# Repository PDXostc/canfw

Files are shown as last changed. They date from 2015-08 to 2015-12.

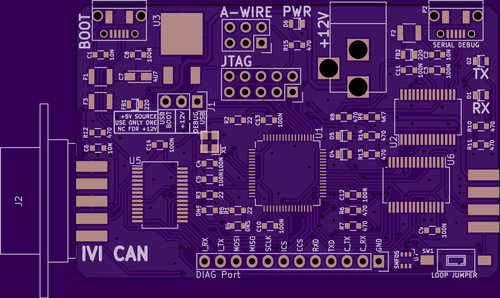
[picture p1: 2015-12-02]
hardware/Project Shares/V1.1 front.png

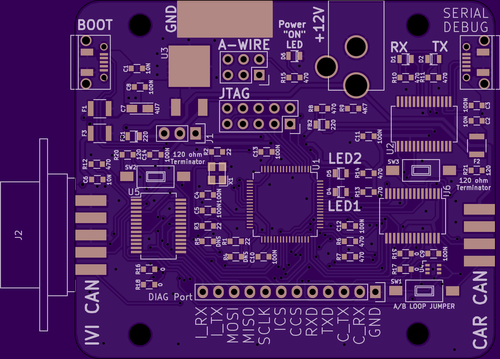
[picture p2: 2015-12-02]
hardware/Project Shares/V1.11 front.png

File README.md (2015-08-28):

# CAN FIREWALL

There are two tables, IVI2VEH and VEH2IVI, specifiying rules for
traffic going from the IVI to the vehicle and from vehicle to IVI.

Each one of the two tables has a number of rules.

Each rule has a numberic ID. Rules are executed in order of ascending IDs.

Each rule has an Frame ID mask and a Frame ID filter, applied
according to the standard CAN bus filter principle, as described 
[here](http://www.cse.dmu.ac.uk/~eg/tele/CanbusIDandMask.html).

Below is pseudo code for frame processing.

    process_frame(frame_id, payload) {

      // Traverse all rules
      for (i in rules) {
	    masked_id = (frame_id & rules[i].id_mask);

	    // If the masked out ID is 0, we have a hit. Process
        if (!masked_id) {
	      process(frame_id, input, rules[i].action,
		          rules[i].id_operand, rules[i].data_operand);
	      return;
	    }

        // Check if we have a hit on the masked ID and the
		// ID filter.
	    // If so, we have a hit and will process
	    if (masked_id & rules[i].id_filter) {
	      process(frame_id, input, rules[i].action,
		          rules[i].id_operand, rules[i].data_operand);
	      return;
	    }

        // No hit. Try next rule
	  }

	  // No rule matched. Forward unmodified frame
      process(frame_id, input, ID_AND_DATA_AND,
	          0xFFFFFFFF, 0xFFFFFFFFFFFFFFFF);

	  return ok;
    }

Below is an example of a rule table.

ID | IdMask     |   IdFilter | Action          | IdOperand  | DataOperand        |
---|------------|------------|-----------------|------------|--------------------|
1  | 0xFFFFFFFF | 0x00000012 | ID_AND_DATA_OR  | 0x00FFFFFF | 0x000000FFFFFFFFFF |
2  | 0xFFFFFFF0 | 0x00000120 | ID_SET_DATA_SET | 0x01234567 | 0x0123456780ABCDEF |
99 | 0x00000000 | 0x00000000 | BLOCK           | 0x00000000 | 0x0000000000000000 |

* **RULE 1**<br>
  Rule ID 1 specifies will filter out the lower all bits of the CAN
  frame ID and match those against the specific ID 0x12, thus intercepting
  all CAN frames with the exact ID of 0x00000012.<br>
  An intercepted frame will be forwarded to the other side after ANDing
  the incoming Frame ID with ```0x00FFFFFF```, and then ORing the
  data payload with ```0x000000FFFFFFFFFF```.<br>
  Once the intercepted frame has been forwarded, the next frame is processed.

* **RULE 2**<br>

  Rule ID 2 is evaluated for all frames not intercepted by Rule 1 above.
  The rule will mask the incoming CAN frame ID against ```0xFFFFFFF0```
  and filter the result against ```0x00000120```, intercepting all
  CAN frames between ```0x00000120``` and ```0x0000012F```.<br>
  For each frame intercetpted by rule 2, a fixed frame will be sent to the other side
  with the frame ID ```0x01234567``` and payload ```0x0123456780ABCDEF```.

* **RULE 99**<br>
  Rule 99, a catch all, has a mask that intercepts all frames not intercepted
  by rule 1 or 2. Since the mask is ```0x00000000```, the filter will not be
  used since there no bits will pass the mask to be applied to the filter.<br>
  Rule 99 will block the frame and not send anything to the other side.<br>
  The modification bitmasks for the frame ID and data payload are unused 
  for blocking rules.

Please see presentation under doc for further details.

Hardware Details and Data sheets:
AT32UC3C2512C Datasheet http://www.mouser.com/ds/2/36/doc32117-74889.pdf

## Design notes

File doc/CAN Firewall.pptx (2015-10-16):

## CAN Bus Firewall

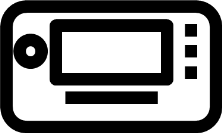
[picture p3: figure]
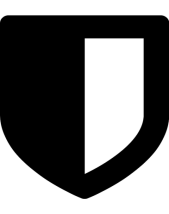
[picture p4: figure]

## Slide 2

Purpose

Ensure compromised IVIs
cannot disrupt
safety critical systems

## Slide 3

Overview

IVI

CAN
Firewall

ECU 1

ECU 2

IVI
Runs a wide variety of software that may be compromised through telematics link
CAN Firewall
Hardware microcontroller on CAN bus filtering CAN traffic based on configurable rules
ECUs
Safety-critical vehicle controllers managing breaks, throttle, steering, etc.

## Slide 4

Northbound vs. Southbound Traffic

Northbound traffic

Forward CAN frame to IVI

Validate CAN frame against rule table

Receive CAN Frame from Vehicle

Southbound traffic

Receive CAN frame from IVI

Validate CAN frame against rule table

Forward CAN Frame to Vehicle

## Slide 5

Use Case: Update rules

A new firewall rule is created and is signed using device-specific key
Rule is pushed over the air to the IVI
IVI Firewall Manager forwards the signed rule to the firewall as a specific CAN frame
Firewall validates signature of received frame and stores new rule.

Backend Server

Rule Admin

Firewall Manager

IVI

Firewall

Rule Manager

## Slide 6

Rule Structure [1/2]

Mask | Filter | ID XForm | Data XForm | ID Operand | Data Operand
0xFFFFFFFF | 0x00000012 | AND | OR | 0x00FFFFFF | 0x000000FFFFFFFFFF

Only bits set in the mask will be matched against the filter
Filter
ANDed against the masked Frame ID of incoming frame
Frame IDs passing filter are intercepted
Frame ID of an incoming frame is masked against rule mask
Mask

See http://www.cse.dmu.ac.uk/~eg/tele/CanbusIDandMask.html for details

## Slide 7

Rule Structure [2/2]

Mask | Filter | ID XForm | Data XForm | ID Operand | Data Operand
0xFFFFFFFF | 0x00000012 | AND | OR | 0x00FFFFFF | 0x000000FFFFFFFFFF

ID XForm
Determines transformation applied to outbound Frame ID (SET, AND, OR, XOR, INV)
ID Operand
Transformation operand applied to outbound Frame ID
Data Operand
Transformation operand applied to outbound Data
Data XForm
Determines transformation applied to outbound Data (SET, AND, OR, XOR, INV)

A Rule can also specify that the frame is to be silently dropped or passed as is.

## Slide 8

CAN Rule Table

Prio | Mask | Filter | ID XForm | Data XForm | ID Operand | Data Operand
0x01 | 0xFFFFFFFF | 0x00000012 | AND | OR | 0x00FFFFFF | 0x000000FFFFFFFFFF
0x02 | 0xFFFFFFF0 | 0x00000120 | SET | SET | 0x01234567 | 0x0123456780ABCDEF
0x7E | 0x00000000 | 0x00000000 | DROP | DROP | 0x00000000 | 0x0000000000000000

Prioritize
Rules are applied to incoming frames in order of ascending priority
Match and process
A rule-matching frame is processed by that rule and is then forwarded to its destination
Forward to next rule
A non-matching frame passed on to the rule with the next ascending ID

If no rule matches, the frame is forwarded unmodified to its destination

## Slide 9

CAN Rule Configuration – Common Header

Frame ID | Data: Prio [1] | Data: Cmd [1] | … | …
0x00004711 | 0x04 | [RULE] | … | …

Frame ID [32 bits]
Factory-configured CAN Frame that is intercepted and interpreted by the CAN Firewall.
Prio [0x00-0x7F | 0x80-0xFF] [1 byte]
Specifies the priority of the rule that is being prepared and which .
0x00-0x7F applies to northbound traffic. 0x80-0xFF applies to southbound traffic.
All commands setting up and storing a single rule will use the same Prio.
Cmd [PREP_RULE1, PREP_RULE2, PREP_RULE3 , PREP_RULE4, PREP_RULE5,PREP_RULE6, STORE_RULE] [1 byte]
Sets up a single rule. PREP_RULE1 – PREP_RULE6 are transmitted with the same Prio. STORE_RULE is then transmitted with the given Prio to store the single rule specified by the previous PREP rule commands.

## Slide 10

CAN Rule Configuration – PREP_RULE1

Frame ID | Prio [1] | Cmd [1] | Mask [4] | XForm [1] | Rsvd [1]
0x00004711 | 0x04 | 0x01 | 0x0000FFFF | 0x01 | 0x00

Cmd [PREP_RULE1] [1 byte]
PREP_RULE1 specifies the rule priority and the mask to apply, and the transform operators for the rule.
XForm [SET_AND] [1 byte]
The transformation to apply to Frame ID and Data. Combination of SET, AND, OR, XOR, and NEG. Upper four bits defines Frame ID operator. Lower four bits defines Data operator.
Mask [32 bit value] [4 bytes]
Mask to apply to incoming Frame ID prior to filtering.
Reserved for future use. Set to 0

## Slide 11

CAN Rule Configuration – PREP_RULE2

Frame ID | Prio [1] | Cmd [1] | Filter [4] | DtOper1 [2]
0x00004711 | 0x04 | 0x02 | 0x0000AAC1 | 0x0001

Cmd [PREP_RULE2] [1 byte]
PREP_RULE2 specifies the filter to apply to incoming Frame IDs and the low 16 bits of the Data transformation operand
DtOper1 [16 bit value] [2 bytes]
Specifies the little endian bits 0-15 of the data operand to provide to the data transform operator (AND, OR, XOR, NEG).
Filter [4] [32 bit value] [4 bytes]
Filter to apply to incoming Frame ID that has been masked.

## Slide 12

CAN Rule Configuration – PREP_RULE3

Frame ID | Prio [1] | Cmd [1] | DtOper2 [6]
0x00004711 | 0x04 | 0x03 | 0x020304050607

Cmd [PREP_RULE3] [1 byte]
PREP_RULE2 specifies the high 48 bits of the operand to apply to the payload transform operator.
DtOper2 [48 bit value] [6 bytes]
Specifies little endian bits 16-63 of the data operand to provide to the data transform operator (AND, OR, XOR, NEG).
DtOper1 and DtOper2 in the example above are concatenated to: 0x0706050403020100

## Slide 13

CAN Rule Configuration – PREP_RULE4

Frame ID | Prio [1] | Cmd [1] | IDOper [4] | HMAC1 [2]
0x00004711 | 0x04 | 0x04 | 0xFFFF0000 | 0x0001

Cmd [PREP_RULE4] [1 byte]
Specifies the Frame ID operand and the lowest2 bytes of the HMAC-SHA256 signature
HMAC1 [16 bit value] [2 bytes]
Specifies little endian bits 0-15 bits of the HMAC-SHA256 signature, generated with the key flashed into the Firewall at the factory.
IDOper [32 bit value] [4 bytes]
Specifies the Frame ID operand to provide to the Frame ID transform operator

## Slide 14

CAN Rule Configuration – PREP_RULE5

Frame ID | Prio [1] | Cmd [1] | HMAC2 [6]
0x00004711 | 0x04 | 0x05 | 0x020304050607

Cmd [PREP_RULE5] [1 byte]
Specifies six bytes of the HMAC-SHA256 signature
HMAC2 [48 bit value] [6 bytes]
Specifies little endian bits 16-63 of the HMAC-SHA256 signature

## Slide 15

CAN Rule Configuration – PREP_RULE6

Frame ID | Prio [1] | Cmd [1] | HMAC3 [6]
0x00004711 | 0x04 | 0x06 | 0x08090A0B0C0D

Cmd [PREP_RULE6] [1 byte]
Specifies six bytes of the HMAC-SHA256 signature
HMAC3 [48 bit value] [6 bytes]
Specifies little endian bits 64-111 of the HMAC-SHA256 signature

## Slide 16

CAN Rule Configuration – PREP_RULE7

Frame ID | Prio [1] | Cmd [1] | HMAC4 [6]
0x00004711 | 0x04 | 0x07 | 0x0E0F10111213

Cmd [PREP_RULE7] [1 byte]
Specifies six bytes of the HMAC-SHA256 signature
HMAC4 [48 bit value] [6 bytes]
Specifies little endian bits 112-159 of the HMAC-SHA256 signature

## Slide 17

CAN Rule Configuration – PREP_RULE8

Frame ID | Prio [1] | Cmd [1] | HMAC5 [6]
0x00004711 | 0x04 | 0x08 | 0x141516171819

Cmd [PREP_RULE8] [1 byte]
Specifies six bytes of the HMAC-SHA256 signature
HMAC5 [48 bit value] [6 bytes]
Specifies little endian bits 160-207 of the HMAC-SHA256 signature

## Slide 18

CAN Rule Configuration – PREP_RULE9

Frame ID | Prio [1] | Cmd [1] | HMAC6 [6]
0x00004711 | 0x04 | 0x09 | 0x1A1B1C1D1E1F

Cmd [PREP_RULE9] [1 byte]
Specifies six bytes of the HMAC-SHA256 signature
HMAC6 [48 bit value] [6 bytes]
Specifies little endian bits 208-255 of the HMAC-SHA256 signature

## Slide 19

CAN Rule Configuration – STORE_RULE

Frame ID | Prio [1] | Cmd [1] | Seq [4] | Unused [2]
0x00004711 | 0x04 | 0x10 | 0x00000001 | 0x0000

Cmd [STORE_RULE] [1 byte]
Stores the rule specified by PREP_RULE1 to PREP_RULE6
Seq [32 bit value] [4 byte]
Unique sequence number for this given Prio. Value must be greater than previously received value for the given Prio in order for the rule to be processed. Stops replay attacks.
Unused [16 bit value] [2 bytes]
Not used. Must be 0x0000

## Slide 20

CAN Rule Configuration – Example

Frame ID | Prio | Cmd | Command Parameters

0x00004711 | 0x04 | 0x01 [PREP_RULE1] | Mask: 0x0000FFFF | XForm: 0x01 | Rsvd: 0x00

0x00004711 | 0x04 | 0x02 [PREP_RULE2] | Filter: 0x0000AAC1 | DtOper1: 0x0001

0x00004711 | 0x04 | 0x03 [PREP_RULE3] | DtOper2: 0x020304050607

0x00004711 | 0x04 | 0x04 [PREP_RULE4] | IDOper: 0xFFFF0000 | HMAC1: 0x0001

0x00004711 | 0x04 | 0x05 [PREP_RULE5] | HMAC2: 0x020304050607

0x00004711 | 0x04 | 0x06 [PREP_RULE6] | HMAC3: 0x08090A0B0C0D

0x00004711 | 0x04 | 0x07 [PREP_RULE7] | HMAC4: 0x0E0F10111213

0x00004711 | 0x04 | 0x08 [PREP_RULE8] | HMAC5: 0x141516171819

0x00004711 | 0x04 | 0x09 [PREP_RULE9] | HMAC6: 0x1A1B1C1D1E1F

0x00004711 | 0x04 | 0x10 [STORE_RULE] | Seq: 0x00000001 | Unused: 0x0000

Prio | Mask | Filter | ID XForm | Data XForm | ID Operand | Data Operand
0x04 | 0x0000FFFFF | 0x0000AAC1 | SET | AND | 0xFFFF0000 | 0x0706050403020100

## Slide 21

Signature Payload used by HMAC-SHA256

Frame ID | Prio | Cmd | Command Parameters

0x00004711 | 0x04 | 0x01 [PREP_RULE1] | Mask: 0x0000FFFF | XForm: 0x01 | Rsvd: 0x00

0x00004711 | 0x04 | 0x02 [PREP_RULE2] | Filter: 0x0000AAC1 | DtOper1: 0x0001

0x00004711 | 0x04 | 0x03 [PREP_RULE3] | DtOper2: 0x020304050607

0x00004711 | 0x04 | 0x04 [PREP_RULE4] | IDOper: 0xFFFF0000 | HMAC1: 0x0001

0x00004711 | 0x04 | 0x05 [PREP_RULE5] | HMAC2: 0x020304050607

0x00004711 | 0x04 | 0x10 [STORE_RULE] | Seq: 0x00000001 | Unused: 0x0000

Prio | Mask | XForm | Rsvd | Filter | Data Operand | ID Operand | Sequence | Unused
0x04 | 0x0000FFFF | 0x01 | 0x00 | 0x0000AAC1 | 0x0706050403020100 | 0xFFFF0000 | 0x00000001 | 0x0000

Signature Payload string [31 bytes] (Color coded fields)
0x040000FFFF01000000AAC10706050403020100FFFF0000000000010000

…

## Thank You

Magnus Feuer

Lead System Architect – Open Software Initiative
mfeuer@jaguarlandrover.com
+1-949-294 7871

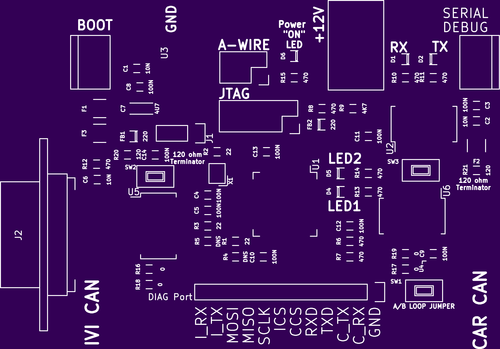
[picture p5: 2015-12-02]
hardware/Project Shares/V1.11 silk.png

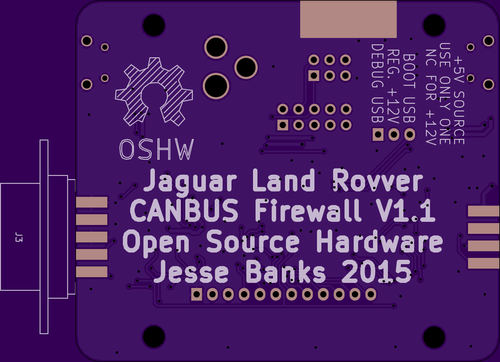
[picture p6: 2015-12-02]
hardware/Project Shares/V1.11 back.png

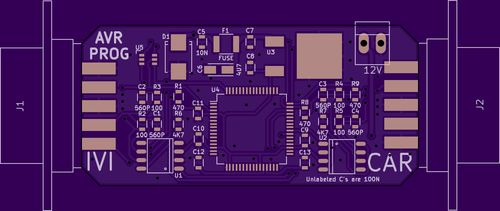
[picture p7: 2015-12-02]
hardware/Project Shares/V1.01 front.png

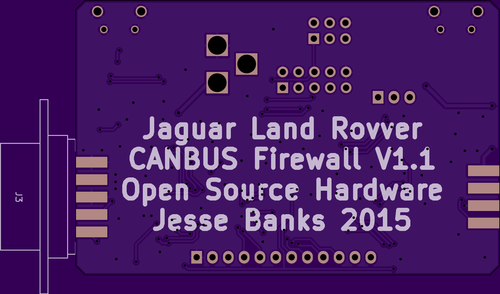
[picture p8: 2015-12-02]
hardware/Project Shares/V1.1 back.png

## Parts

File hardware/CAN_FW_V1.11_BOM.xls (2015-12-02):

 |  | Mouser # | Mfr. # | Manufacturer | Desc. | RoHS | Lifecycle | Customer Part # | Order Qty. |  |  |  |  | Price (USD)
 |  | Shunt | JMP | 571-28815452 | 2-881545-2 | TE Connectivity | Headers & Wire Housings POST SHUNT 2 POS | RoHS Compliant |  |  | 1 | $0.14 | $0.14 | 0.14 | 0.14
C1 | 10N | C1 | 10N | 77-VJ0603Y103KXACBC | VJ0603Y103KXACW1BC | Vishay | Multilayer Ceramic Capacitors MLCC - SMD/SMT 0603 0.01uF 50volts X7R 10% | RoHS Compliant |  |  | 3 | $0.06 | $0.18 | 0.06 | 0.06
C10 | 100N | C10 | 100N | 77-VJ0603Y104JXJPBC | VJ0603Y104JXJPW1BC | Vishay | Multilayer Ceramic Capacitors MLCC - SMD/SMT 0603 0.1uF 16volts X7R 5% | RoHS Compliant |  |  | 10 | $0.10 | $1.00 | 0.10 | 0.10
C11 | 100N | C11 | 100N | 77-VJ0603Y104JXJPBC | VJ0603Y104JXJPW1BC | Vishay | Multilayer Ceramic Capacitors MLCC - SMD/SMT 0603 0.1uF 16volts X7R 5% | RoHS Compliant |  |  | 10 | $0.10 | $1.00 | 0.10 | 0.10
C12 | 100N | C12 | 100N | 77-VJ0603Y104JXJPBC | VJ0603Y104JXJPW1BC | Vishay | Multilayer Ceramic Capacitors MLCC - SMD/SMT 0603 0.1uF 16volts X7R 5% | RoHS Compliant |  |  | 10 | $0.10 | $1.00 | 0.10 | 0.10
C13 | 100N | C13 | 100N | 77-VJ0603Y104JXJPBC | VJ0603Y104JXJPW1BC | Vishay | Multilayer Ceramic Capacitors MLCC - SMD/SMT 0603 0.1uF 16volts X7R 5% | RoHS Compliant |  |  | 10 | $0.10 | $1.00 | 0.10 | 0.10
C14 | 100N | C14 | 100N | 77-VJ0603Y104JXJPBC | VJ0603Y104JXJPW1BC | Vishay | Multilayer Ceramic Capacitors MLCC - SMD/SMT 0603 0.1uF 16volts X7R 5% | RoHS Compliant |  |  | 10 | $0.10 | $1.00 | 0.10 | 0.10
C2 | 10N | C2 | 10N | 77-VJ0603Y103KXACBC | VJ0603Y103KXACW1BC | Vishay | Multilayer Ceramic Capacitors MLCC - SMD/SMT 0603 0.01uF 50volts X7R 10% | RoHS Compliant |  |  | 3 | $0.06 | $0.18 | 0.06 | 0.06
C3 | 100N | C3 | 100N | 77-VJ0603Y104JXJPBC | VJ0603Y104JXJPW1BC | Vishay | Multilayer Ceramic Capacitors MLCC - SMD/SMT 0603 0.1uF 16volts X7R 5% | RoHS Compliant |  |  | 10 | $0.10 | $1.00 | 0.10 | 0.10
C4 | 100N | C4 | 100N | 77-VJ0603Y104JXJPBC | VJ0603Y104JXJPW1BC | Vishay | Multilayer Ceramic Capacitors MLCC - SMD/SMT 0603 0.1uF 16volts X7R 5% | RoHS Compliant |  |  | 10 | $0.10 | $1.00 | 0.10 | 0.10
C5 | 100N | C5 | 100N | 77-VJ0603Y104JXJPBC | VJ0603Y104JXJPW1BC | Vishay | Multilayer Ceramic Capacitors MLCC - SMD/SMT 0603 0.1uF 16volts X7R 5% | RoHS Compliant |  |  | 10 | $0.10 | $1.00 | 0.10 | 0.10
C6 | 10N | C6 | 10N | 77-VJ0603Y103KXACBC | VJ0603Y103KXACW1BC | Vishay | Multilayer Ceramic Capacitors MLCC - SMD/SMT 0603 0.01uF 50volts X7R 10% | RoHS Compliant |  |  | 3 | $0.06 | $0.18 | 0.06 | 0.06
C7 | 4U7 | C7 | 4U7 | 581-TAJA475K025RNJ | TAJA475K025RNJ | AVX | Tantalum Capacitors - Solid SMD 25V 4.7uF 10% | RoHS Compliant |  |  | 1 | $0.10 | $0.10 | 0.10 | 0.10
C8 | 100N | C8 | 100N | 77-VJ0603Y104JXJPBC | VJ0603Y104JXJPW1BC | Vishay | Multilayer Ceramic Capacitors MLCC - SMD/SMT 0603 0.1uF 16volts X7R 5% | RoHS Compliant |  |  | 10 | $0.10 | $1.00 | 0.10 | 0.10
C9 | 100N | C9 | 100N | 77-VJ0603Y104JXJPBC | VJ0603Y104JXJPW1BC | Vishay | Multilayer Ceramic Capacitors MLCC - SMD/SMT 0603 0.1uF 16volts X7R 5% | RoHS Compliant |  |  | 10 | $0.10 | $1.00 | 0.10 | 0.10
CON1 | BARREL_JACK | CON1 | BARREL_JACK | 502-RAPC722X | RAPC722X | Switchcraft | DC Power Connectors RT ANGL PWK JK PIN D | RoHS Compliant |  |  | 1 | $1.00 | $1.00 | 1.00 | 1.00
CON2 | AVR-JTAG-10 | CON2 | AVR-JTAG-10 | 855-M20-9760546 | M20-9760546 | Harwin | Headers & Wire Housings 05+05 DIL VERTICAL PIN HEADER TIN | RoHS Compliant |  |  | 1 | $0.36 | $0.36 | 0.36 | 0.36
CON3 | AVR-AW-6 | CON3 | AVR-AW-6 | 855-M20-9980346 | M20-9980346 | Harwin | Headers & Wire Housings 03+03 DIL VERTICAL PIN HEADER TIN | RoHS Compliant |  |  | 1 | $0.22 | $0.22 | 0.22 | 0.22
D1 | RED | D1 | RED | 720-LSR976-NR-1 | LS R976-NR-1 | Osram Opto Semiconductor | Standard LEDs - SMD Super Red, 633nm 180mcd, 20mA | RoHS Compliant |  |  | 2 | $0.10 | $0.20 | 0.10 | 0.10
D2 | BLUE | D2 | BLUE | 710-150080BS75000 | 150080BS75000 | Wurth Electronics | Standard LEDs - SMD WL-SMCW SMDMono TpVw Waterclr 0805 Blue | RoHS Compliant | New Product |  | 3 | $0.29 | $0.87 | 0.29 | 0.29
D3 | SMBJ16A | D3 | SMBJ16A | 511-SMBJ16A | SMBJ16A-TR | STMicroelectronics | TVS Diodes - Transient Voltage Suppressors 600W 16V Unidirect | RoHS Compliant |  |  | 1 | $0.24 | $0.24 | 0.24 | 0.24
D4 | RED | D4 | RED | 720-LSR976-NR-1 | LS R976-NR-1 | Osram Opto Semiconductor | Standard LEDs - SMD Super Red, 633nm 180mcd, 20mA | RoHS Compliant |  |  | 2 | $0.10 | $0.20 | 0.10 | 0.10
D5 | BLUE | D5 | BLUE | 710-150080BS75000 | 150080BS75000 | Wurth Electronics | Standard LEDs - SMD WL-SMCW SMDMono TpVw Waterclr 0805 Blue | RoHS Compliant | New Product |  | 3 | $0.29 | $0.87 | 0.29 | 0.29
D6 | BLUE | D6 | BLUE | 710-150080BS75000 | 150080BS75000 | Wurth Electronics | Standard LEDs - SMD WL-SMCW SMDMono TpVw Waterclr 0805 Blue | RoHS Compliant | New Product |  | 3 | $0.29 | $0.87 | 0.29 | 0.29
F1 | FUSE | F1 | FUSE | 530-0ZCH0050FF2G | 0ZCH0050FF2G | Bel | Resettable Fuses - PPTC Fuse | RoHS Compliant |  |  | 3 | $0.11 | $0.33 | 0.11 | 0.11
F2 | FUSE | F2 | FUSE | 530-0ZCH0050FF2G | 0ZCH0050FF2G | Bel | Resettable Fuses - PPTC Fuse | RoHS Compliant |  |  | 3 | $0.11 | $0.33 | 0.11 | 0.11
F3 | FUSE | F3 | FUSE | 530-0ZCH0050FF2G | 0ZCH0050FF2G | Bel | Resettable Fuses - PPTC Fuse | RoHS Compliant |  |  | 3 | $0.11 | $0.33 | 0.11 | 0.11
FB1 | 220 | FB1 | 220 | 810-MPZ1608S221ATA00 | MPZ1608S221ATA00 | TDK | EMI Filter Beads, Chips & Arrays 220ohms 2.2A 50mOhms 0603 Ferrite Chip | RoHS Compliant | New Product |  | 2 | $0.10 | $0.20 | 0.10 | 0.10
FB2 | 220 | FB2 | 220 | 810-MPZ1608S221ATA00 | MPZ1608S221ATA00 | TDK | EMI Filter Beads, Chips & Arrays 220ohms 2.2A 50mOhms 0603 Ferrite Chip | RoHS Compliant | New Product |  | 2 | $0.10 | $0.20 | 0.10 | 0.10
J1 | +5V_SRC | J1 | +5V_SRC | 855-M20-9990346 | M20-9990346 | Harwin | Headers & Wire Housings 03 SIL VERTICAL PIN HEADER TIN | RoHS Compliant |  |  | 1 | $0.14 | $0.14 | 0.14 | 0.14
J2 | DB9 | J2 | DB9 | 523-L77SDE09S | L77SDE09S | Amphenol | D-Sub Standard Connectors Soc tinned shell 9S solder cup | RoHS Compliant |  |  | 2 | $0.83 | $1.66 | 0.83 | 0.83
J3 | DB9 | J3 | DB9 | 523-L77SDE09S | L77SDE09S | Amphenol | D-Sub Standard Connectors Soc tinned shell 9S solder cup | RoHS Compliant |  |  | 2 | $0.83 | $1.66 | 0.83 | 0.83
P1 | USB_OTG | P1 | USB_OTG | 656-DX4R005JJ2R1800 | DX4R005JJ2R1800 | JAE Electronics | USB Connectors microUSB 2.0 TYPE B STDMNT RCPT W/TAPER | RoHS Compliant |  |  | 2 | $0.74 | $1.48 | 0.74 | 0.74
P2 | USB_OTG | P2 | USB_OTG | 656-DX4R005JJ2R1800 | DX4R005JJ2R1800 | JAE Electronics | USB Connectors microUSB 2.0 TYPE B STDMNT RCPT W/TAPER | RoHS Compliant |  |  | 2 | $0.74 | $1.48 | 0.74 | 0.74
P3 | DIAG Port | P3 | DIAG Port | 855-M20-9991246 | M20-9991246 | Harwin | Headers & Wire Housings 12 SIL VERTICAL PIN HEADER TIN | RoHS Compliant |  |  | 1 | $0.44 | $0.44 | 0.44 | 0.44
R1 | 22 | R1 | 22 | 71-CRCW0603-22.1-E3 | CRCW060322R1FKEA | Vishay | Thick Film Resistors - SMD 1/20watt 22.1ohms 1% 200ppm | RoHS Compliant By Exemption |  |  | 3 | $0.10 | $0.10 | .1 | 0.10
R10 | 470 | R10 | 470 | 71-CRCW0603-470-E3 | CRCW0603470RFKEA | Vishay | Thick Film Resistors - SMD 1/20watt 470ohms 5% 200ppm | RoHS Compliant By Exemption |  |  | 9 | $0.10 | $1.17 | .1 | 0.10
R11 | 470 | R11 | 470 | 71-CRCW0603-470-E3 | CRCW0603470RFKEA | Vishay | Thick Film Resistors - SMD 1/20watt 470ohms 5% 200ppm | RoHS Compliant By Exemption |  |  | 9 | $0.10 | $1.17 | .1 | 0.10
R12 | 470 | R12 | 470 | 71-CRCW0603-470-E3 | CRCW0603470RFKEA | Vishay | Thick Film Resistors - SMD 1/20watt 470ohms 5% 200ppm | RoHS Compliant By Exemption |  |  | 9 | $0.10 | $1.17 | .1 | 0.10
R13 | 470 | R13 | 470 | 71-CRCW0603-470-E3 | CRCW0603470RFKEA | Vishay | Thick Film Resistors - SMD 1/20watt 470ohms 5% 200ppm | RoHS Compliant By Exemption |  |  | 9 | $0.10 | $1.17 | .1 | 0.10
R14 | 470 | R14 | 470 | 71-CRCW0603-470-E3 | CRCW0603470RFKEA | Vishay | Thick Film Resistors - SMD 1/20watt 470ohms 5% 200ppm | RoHS Compliant By Exemption |  |  | 9 | $0.10 | $1.17 | .1 | 0.10
R15 | 470 | R15 | 470 | 71-CRCW0603-470-E3 | CRCW0603470RFKEA | Vishay | Thick Film Resistors - SMD 1/20watt 470ohms 5% 200ppm | RoHS Compliant By Exemption |  |  | 9 | $0.10 | $1.17 | .1 | 0.10
R16 | 0 | R16 | 0 | 71-CRCW0603-0-E3 | CRCW06030000Z0EA | Vishay | Thick Film Resistors - SMD 1/20watt ZEROohm Jumper | RoHS Compliant By Exemption |  |  | 4 | $0.10 | $0.52 | .1 | 0.10
R17 | 0 | R17 | 0 | 71-CRCW0603-0-E3 | CRCW06030000Z0EA | Vishay | Thick Film Resistors - SMD 1/20watt ZEROohm Jumper | RoHS Compliant By Exemption |  |  | 4 | $0.10 | $0.52 | .1 | 0.10
R18 | 0 | R18 | 0 | 71-CRCW0603-0-E3 | CRCW06030000Z0EA | Vishay | Thick Film Resistors - SMD 1/20watt ZEROohm Jumper | RoHS Compliant By Exemption |  |  | 4 | $0.10 | $0.52 | .1 | 0.10
R19 | 0 | R19 | 0 | 71-CRCW0603-0-E3 | CRCW06030000Z0EA | Vishay | Thick Film Resistors - SMD 1/20watt ZEROohm Jumper | RoHS Compliant By Exemption |  |  | 4 | $0.10 | $0.52 | .1 | 0.10
R2 | 22 | R2 | 22 | 71-CRCW020122R1FNED | CRCW020122R1FNED | Vishay | Thick Film Resistors - SMD 1/20watt 22.1ohms 1% 200ppm | RoHS Compliant By Exemption |  |  | 3 | $0.10 | $0.45 | .1 | 0.10
R20 | 120 | R20 | 120 | 71-CRCW0603J-120-E3 | CRCW0603120RJNEA | Vishay | Thick Film Resistors - SMD 1/20watt 22.1ohms 1% 200ppm | RoHS Compliant By Exemption |  |  | 2 | $0.10 | $1.45 | .1 | 0.10
R21 | 120 | R21 | 120 | 71-CRCW0603J-120-E3 | CRCW0603120RJNEA | Vishay | Thick Film Resistors - SMD 1/20watt 22.1ohms 1% 200ppm | RoHS Compliant By Exemption |  |  | 2 | $0.10 | $2.45 | .1 | 0.10
R3 | 22 | R3 | 22 | 71-CRCW020122R1FNED | CRCW020122R1FNED | Vishay | Thick Film Resistors - SMD 1/20watt 22.1ohms 1% 200ppm | RoHS Compliant By Exemption |  |  | 3 | $0.10 | $0.45 | .1 | 0.10
R4 | DNS | R4 | DNS | -- | -- | -- | -- | -- | -- | -- | -- | -- | -- |  | 0.00
R5 | DNS | R5 | DNS | -- | -- | -- | -- | -- | -- | -- | -- | -- | -- |  | 0.00
R6 | 470 | R6 | 470 | 71-CRCW0603-470-E3 | CRCW0603470RFKEA | Vishay | Thick Film Resistors - SMD 1/20watt 470ohms 5% 200ppm | RoHS Compliant By Exemption |  |  | 9 | $0.10 | $1.17 | .1 | 0.10
R7 | 470 | R7 | 470 | 71-CRCW0603-470-E3 | CRCW0603470RFKEA | Vishay | Thick Film Resistors - SMD 1/20watt 470ohms 5% 200ppm | RoHS Compliant By Exemption |  |  | 9 | $0.10 | $1.17 | .1 | 0.10
R8 | 470 | R8 | 470 | 71-CRCW0603-470-E3 | CRCW0603470RFKEA | Vishay | Thick Film Resistors - SMD 1/20watt 470ohms 5% 200ppm | RoHS Compliant By Exemption |  |  | 9 | $0.10 | $1.17 | .1 | 0.10
R9 | 4K7 | R9 | 4K7 | 71-CRCW0603-4.7K-E3 | CRCW06034K70FKEA | Vishay | Thick Film Resistors - SMD 1/10watt 4.7Kohms 1% | RoHS Compliant By Exemption |  |  | 1 | $0.10 | $0.10 | 0.10 | 0.10
SW1 | SPST | SW1 | SPST | 642-DM01 | DM01 | Apem | DIP Switches / SIP Switches SPST 0.025A 24VDC | RoHS Compliant |  |  | 1 | $1.10 | $1.10 | 1.10 | 1.10
SW2 | SPST | SW2 | SPST | 642-DM01 | DM01 | Apem | DIP Switches / SIP Switches SPST 0.025A 24VDC | RoHS Compliant |  |  | 1 | $1.10 | $1.10 | 1.10 | 1.10
SW3 | SPST | SW3 | SPST | 642-DM01 | DM01 | Apem | DIP Switches / SIP Switches SPST 0.025A 24VDC | RoHS Compliant |  |  | 1 | $1.10 | $1.10 | 1.10 | 1.10
U1 | AT32UC3C | U1 | AT32UC3C | 556-AT32UC3C2512CA2T | AT32UC3C2512C-A2UT | Atmel | 32-bit Microcontrollers - MCU UC3C 512K FLASH 64K SRAM | RoHS Compliant |  |  | 1 | $14.74 | $14.74 | 14.74 | 14.74
U2 | FT232RL-SSOP | U2 | FT232RL-SSOP | 895-FT232RL | FT232RL-REEL | FTDI | USB Interface IC USB to Serial UART Enhanced IC SSOP-28 | RoHS Compliant |  |  | 1 | $4.50 | $4.50 | 4.50 | 4.50
U3 | MC78M05CDT | U3 | MC78M05CDT | 511-L78M05CDT-TR | L78M05CDT-TR | STMicroelectronics | Linear Voltage Regulators 5.0V 0.5A Positive | RoHS Compliant |  |  | 1 | $0.42 | $0.42 | 0.42 | 0.42
U4 | SMF05 | U4 | SMF05 | 863-SMF05CT2G | SMF05CT2G | ON Semiconductor | TVS Diode Arrays 5 Line TVS Array | RoHS Compliant |  |  | 1 | $0.57 | $0.57 | 0.57 | 0.57
U5 | MCP25625 | U5 | MCP25625 | 579-MCP25625-E/SS | MCP25625-E/SS | Microchip | CAN Interface IC CAN Controller with Int. Transceiver | RoHS Compliant | New At Mouser |  | 2 | $2.76 | $5.52 | 2.76 | 2.76
U6 | MCP25625 | U6 | MCP25625 | 579-MCP25625-E/SS | MCP25625-E/SS | Microchip | CAN Interface IC CAN Controller with Int. Transceiver | RoHS Compliant | New At Mouser |  | 2 | $2.76 | $5.52 | 2.76 | 2.76
X1 | TXC | X1 | TXC | 998-1001DI2-016.0000 | DSC1001DI2-016.0000 | Micrel | Standard Clock Oscillators Oscillator, Low Power, -40C-85C, 25ppm | RoHS Compliant | New Product |  | 1 | $2.10 | $2.10 | 2.10 | 2.10
 |  |  |  |  |  |  |  |  |  |  |  |  |  | Each(ish) | $41.61

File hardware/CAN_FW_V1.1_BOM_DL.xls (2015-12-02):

CAN Firewall
Mouser # | Mfr. # | Manufacturer | Desc. | RoHS | Lifecycle | Customer Part # | Order Qty. | Price (USD) | Ext.: (USD)
863-SMF05CT2G | SMF05CT2G | ON Semiconductor | TVS Diode Arrays 5 Line TVS Array | RoHS Compliant |  |  | 1 | $0.562 | $0.56
556-AT32UC3C2512CA2T | AT32UC3C2512C-A2UT | Atmel | 32-bit Microcontrollers - MCU UC3C 512K FLASH 64K SRAM | RoHS Compliant |  |  | 1 | $14.54 | $14.54
530-0ZCH0050FF2G | 0ZCH0050FF2G | Bel | Resettable Fuses - PPTC Fuse | RoHS Compliant | New At Mouser |  | 1 | $0.118 | $0.12
77-VJ0603Y103KXACBC | VJ0603Y103KXACW1BC | Vishay | Multilayer Ceramic Capacitors MLCC - SMD/SMT 0603 0.01uF 50volts X7R 10% | RoHS Compliant |  |  | 1 | $0.059 | $0.06
523-L77SDE09S | L77SDE09S | Amphenol | D-Sub Standard Connectors Soc tinned shell 9S solder cup | RoHS Compliant |  |  | 2 | $0.857 | $1.71
581-TAJA475K025RNJ | TAJA475K025RNJ | AVX | Tantalum Capacitors - Solid SMD 25V 4.7uF 10% | RoHS Compliant |  |  | 1 | $0.11 | $0.11
80-C0603C561J5G | C0603C561J5GACTU | Kemet | Multilayer Ceramic Capacitors MLCC - SMD/SMT 50volts 560pF C0G 5% | RoHS Compliant |  |  | 4 | $0.11 | $0.44
667-ERJ-3EKF1000V | ERJ-3EKF1000V | Panasonic | Thick Film Resistors - SMD 0603 100ohms 1% Tol | RoHS Compliant By Exemption |  |  | 4 | $0.099 | $0.40
511-SMBJ16A | SMBJ16A-TR | STMicroelectronics | TVS Diodes - Transient Voltage Suppressors 600W 16V Unidirect | RoHS Compliant |  |  | 1 | $0.237 | $0.24
511-L78M05CDT-TR | L78M05CDT-TR | STMicroelectronics | Linear Voltage Regulators 5.0V 0.5A Positive | RoHS Compliant |  |  | 1 | $0.414 | $0.41
77-VJ0603Y104JXJPBC | VJ0603Y104JXJPW1BC | Vishay | Multilayer Ceramic Capacitors MLCC - SMD/SMT 0603 0.1uF 16volts X7R 5% | RoHS Compliant |  |  | 7 | $0.099 | $0.69
71-CRCW0603-4.7K-E3 | CRCW06034K70FKEA | Vishay | Thick Film Resistors - SMD 1/10watt 4.7Kohms 1% | RoHS Compliant By Exemption |  |  | 2 | $0.099 | $0.20
579-MCP2551-I/SN | MCP2551-I/SN | Microchip | CAN Interface IC Hi Spd CAN Transceiv | RoHS Compliant |  |  | 2 | $1.16 | $2.32

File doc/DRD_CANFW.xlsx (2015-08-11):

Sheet: Contents
JLR PoC Design Requirements Document
TITLE OF FEATURE | CAN Firewall (CANFW)
Feature Summary | The project objective is to develop a hardware-based CAN Firewall that can be programmed over the air from a backend server to prohibit a compromised IVI from interfering with safety-critical systems.
What is the User Experience? | The fleet firewall administrator has a website where rules can be provisioned and pushed (via RVI) to the vehicles.
Why is the feature needed? | Today a hacked IVI has full access to all vehicle systems (brakes, steering, throttle, etc) via the CAN bus. The CAN Firewall will mitigate the effect of a rogue IVI.
TABLE OF CONTENTS | Notes | STATUS - RAG
Feature Area Description (FAD)
Use_cases
HMI Flows & Screens (FAD)
HMI_Flow
Graphical Assets (FAD)
List of Graphical Assests
Design Prerequisites (DPR)
HW & SW Prerequisites
Design Prerequisites (DPR) - System Architecture
System Architecture Block Diagram
Software Requirements Specification - Diagram
Software Module Block Diagram
Software Requirements Specification - Requirements Specification
Software Requirements Specification

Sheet: FAD-Use_cases
JLR Feature Area Description (FAD)
Use Case ID | Subsection | Use Case Title | Purpose | Actor(s) | Preconditions | Use Case Steps | Flow Type | Comments
<Use Case Identifier. Includes: UC_<acronym identifier>_####(.#)> | <What feature, subsystem the use case falls under.> | <Identify the name of the use case. It should begin with a verb or an action phrase. (e.g. Request a Template). > | <Provide a high-level description or goal of the use case, typically a couple of sentences. > | <List the Actor, or Actors involved in this Use Case as defined by someone or something that interacts with, or uses, the system to achieve a desired goal.> | <List anything that must be complete prior to the initiation of the use case. For example, the user may be required to be logged into the software application or system. Document as a bulleted list of Preconditions. > | <A detailed list of Main, Alternate, and/or Exception steps followed through to the successful or unsuccessful end of the use case.> | <Name of the flow type: Main: Happy Path - The main flow of events when everything goes as planned. Alternate: A step or sequence of steps that achieves the use case’s goal following different steps than described in the main success scenario. But the goal is finally achieved. Exception: Anything that leads to NOT achieving the use case’s goal.> | <Notes, comments, questions, findings, etc.>
 | Web Admin | List rules for vehicle
 | Web Admin | Edit single rule for vehicle
 | Web Admin | Push rule to vehicle
 | Web Admin | [More]
 | IVI FW Manager | Receive new rule from server via RVI
 | IVI FW Manager | Push received rule to CANFW via CAN bus.
 | IVI FW Manager | [more]
 | FW Firmware | Process northbound traffic
 | FW Firmware | Process southbound traffic
 | FW Firmware | Intercept using default rule
 | FW Firmware | Process PREP_RULE1 frame
 | FW Firmware | Process PREP_RULE2 frame
UC_03 | FW Firmware | Process PREP_RULE3 frame
UC_04 | FW Firmware | Process PREP_RULE4 frame
UC_05 | FW Firmware | Process PREP_RULE5 frame
UC_06 | FW Firmware | Process PREP_RULE6 frame
UC_07 | FW Firmware | Process STORE_RULE frame
UC_08
UC_09
UC_10
UC_11

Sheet: FAD-HMI_Flow
JLR PoC Master HMI Flow Diagram

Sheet: FAD-Graphical_Assets
PoC List of HMI Graphical Assets
File Name [1st Theme] (e.g. BLUE THEME) | File Type | File Size | File Location | Date Updated | Comments
BLUE_Example_image.png | PNG | 6 KB | BaseFileDirectory/ | 2014-03-25
Note to author: include the following rows below the app-specific assets to describe the common top & bottom bars. Edit to replace "app\" with the specific name, add dates, and add the pathname of the Commons DRD doc. Then delete this row.
icon.png | PNG |  | app\css\user\blue\
Common Assets (top, bottom bar, keyboard, audio slider)
BLUE THEME | File Type | File Size | File Location | Date Updated | Comments
common_graphical_assets.zip
Top Bar
icon_settings_blue.png | PNG | 5KB | css/car/components/topBarIcons/images/icon_settings_blue.png | 2014-05-12
top_bar_icons_bg_blue.png | PNG | 5KB | css/user/blue/images/topbaricons/top_bar_icons_bg_blue.png | 2014-05-12
Bottom Bar
icon_back.png | PNG | 2KB | css/user/blue/images/bottombaricons/icon_back.png | 2014-05-12
panel_bottom_blue.png | PNG | 25KB | css/user/blue/images/bottombaricons/panel_bottom_blue.png | 2014-05-12
Keyboard Graphical Assets
default.png | PNG | 2k | Keyboard/css/images/default.png | 2014-05-05
default_icon.png | PNG | 57k | Keyboard/css/images/default_icon.png | 2014-05-05
load.gif | PNG | 2k | Keyboard/css/images/load.gif | 2014-05-05
shift_off_icon.png | PNG | 2k | Keyboard/css/images/shift_off_icon.png | 2014-05-05 | **NOTE All keyboard assests are white and only require one version for both themes
shift_on_icon.png | PNG | 2k | Keyboard/css/images/shift_on_icon.png | 2014-05-05
space_bar_icon.png | PNG | 2k | Keyboard/css/images/space_bar_icon.png | 2014-05-05
symbols_icon.png | PNG | 2k | Keyboard/css/images/symbols_icon.png | 2014-05-05
symbols_off_icon.png | PNG | 2k | Keyboard/css/images/symbols_off_icon.png | 2014-05-05
symbols_set1_icon.png | PNG | 2k | Keyboard/css/images/symbols_set1_icon.png | 2014-05-05
symbols_set2_icon.png | PNG | 2k | Keyboard/css/images/symbols_set2_icon.png | 2014-05-05
white_return.png | PNG | 2k | Keyboard/css/images/white_return.png | 2014-05-05
backspace_icon.png | PNG | 2k | Keyboard/css/images/backspace_icon.png | 2014-05-05
Common Audio Settings Graphical Assets
audio_settings2.png | PNG | 5 KB | AudioSettings/images/ | 2014-05-05
icon_volume_blue.png | PNG | 2KB | AudioControl/css/user/blue/images/progressBar/icon_volume_blue.png | 2014-05-05
progresbarbgstart.png | PNG | 1KB | AudioControl/css/user/blue/images/progressBar/progresbarbgstart.png | 2014-05-05
handle_blue.png | PNG | 3KB | AudioControl/css/user/blue/images/progressBar/handle_blue.png | 2014-05-05
progresbarbg.png | PNG | 1KB | AudioControl/css/user/blue/images/progressBar/progresbarbg.png | 2014-05-05
bt_close.png | PNG | 2k | car/images/bt_close.png | 2014-05-05 | All following assets are all white and theme independant
bt_next.png | PNG | 2k | car/images/bt_next.png | 2014-05-05
bt_pause.png | PNG | 2k | car/images/bt_pause.png | 2014-05-05
bt_play.png | PNG | 2k | car/images/bt_play.png | 2014-05-05
bt_previous.png | PNG | 2k | car/images/bt_previous.png | 2014-05-05

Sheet: Design_PreRequisites_DPR
JLR PoC Design Prerequisites (DPR)
Prerequisite Title | Prerequisite Description | Attachments (Additional Documents)

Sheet: DPR_Architecture_Diagram
JLR PoC Design Prerequisites (DPR) - System Architecture Diagram

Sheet: SoftwareReqSpec_SWRS
Software Requirements Specification - SWRS
 |  |  | Secction | Description
 |  |  | SRV- | Requirements on the rule provisioning web server [ANSON]
 |  |  | MGR- | Requirements on the firewall manager code on the IVI
 |  |  | FW- | Firewall requirements
 |  |  | Phase | Description
 |  |  | FIRST | Initial version of the firewall system
 |  |  | FUTURE1 | Future phases
 |  |  | FUTURE2
 |  |  | FUTURE3
 |  |  | FUTURE4
SERVER REQUIREMENTS
Requirment ID | Man Days | Phase | Heading | Requirement Description | Notes | Attachments (Additional Documents) | Spec Ref
SRV |  |  | Server requirements
SRV-1 |  | FIRST |  | The server shall be used to provision CAN Firewall rules
SRV-2 |  | FIRST |  | The server shall be used to provision vehicles that can receive the rules
SRV-3 |  | FIRST |  | The server shall be able to push a single rule to a set of vehicles
SRV-4 |  | FIRST |  | The server shall keep track of which rules are pushed to which vehicles.
 |  |  |  | [MORE]
SRV-RULE |  |  | Server Rule Management
SRV-RULE-1 |  | FIRST |  | A rule shall either be specified for northbound or southbound traffic
SRV-RULE-2 |  | FIRST |  | A northbound rule shall be applied to CAN traffic sent from the vehicle (secure) to the IVI (insecure)
SRV-RULE-3 |  | FIRST |  | A southbound rule shall be applied to CAN traffic sent from the IVI (insecure) to the IVI (secure)
SRV-RULE-4 |  | FIRST |  | A rule shall be specified with a bit mask
SRV-RULE-5 |  | FIRST |  | A rule shall be specified with a bit filter
SRV-RULE-6 |  | FIRST |  | [MORE FROM PRESENTATION]
SRV-RULE-7 |  | FIRST
SRV-VEHICLE |  |  | Server Vehicle Management
SRV-VEHICLE-1 |  | FIRST |  | The server shall manage up to 50 vehicles
SRV-VEHICLE-2 |  | FIRST |  | A vehicle shall be identified by its VIN
SRV-VEHICLE-3 |  | FIRST |  | The server shall maintain a list of all currently installed rules for each vehicle
SRV-VEHICLE-4 |  | FIRST |  | The server shall be able to push a select number of rules to a select number of vehicles
SRV-VEHICLE-5 |  | FIRST |  | Rules shall be pushed to the vehicle using RVI
 |  |  |  | [MORE]
FIREWALL MANAGER REQUIREMENTS
Requirment ID | Man Days | Phase | Heading | Requirement Description | Notes | Attachments (Additional Documents) | Spec Ref
MGR |  |  | IVI - Firewall manager
MGR-1 |  | FIRST |  | The firewall manager shall execute on an IVI
MGR-2 |  | FIRST |  | The firewall manager shall receive firewall rules from the server
MGR-3 |  | FIRST |  | Rules shall receive rules via RVI
MGR-4 |  | FIRST |  | The firewall manager shall forward received rules to the CAN Firewall
MGR-5 |  | FIRST |  | Forwardning to the CAN Firewall shall be done using the CAN frames described in [CAN PROTOCOL SPEC]
MGR-6 |  | FIRST |  | [MORE]
Firewall Firmware requirements
Requirment ID | Man Days | Phase | Heading | Requirement Description | Notes | Attachments (Additional Documents) | Spec Ref
FW |  |  | Firewall requirements
FW-1 |  | FIRST |  | The firewall shall execute on a dedicated microcontroller
FW-2 |  | FIRST |  | [MORE]
FW-PROV |  |  | Firewall Provisioning
FW-PROV-1 |  | FIRST |  | The Firewall shall have its firmware flashed via dedicated pins that have no other functions
FW-PROV-2 |  | FIRST |  | Firmware flashing shall include the code to execute
FW-PROV-3 |  | FIRST |  | Firmware flashing shall include the cryptographic key to validate HMAC-SHA1 signatures against
FW-PROV-4 |  | FIRST |  | Firmware flashing shall include the CAN Frame ID to listen to for rule updates.
FW-PROV-5 |  | FIRST |  | Firmware flashing shall include a default southbound rule
FW-PROV-6 |  | FIRST |  | Firmware flashing shall include a default northbound rule
FW-PROV-7 |  | FIRST |  | [MORE]
FW-PROV-8 |  | FIRST
FW-PROV-9 |  | FIRST
FW-PROV-10 |  | FIRST
FW-UPDATE |  |  | Firewall Rule updates
FW-UPDATE-1 |  | FIRST |  | New and updated rules shall be programmable into the firewall
FW-UPDATE-2 |  | FIRST |  | Up to 16 rules shall be programmed for northbound traffic
FW-UPDATE-3 |  | FIRST |  | Up to 16 rules shall be programmed for southbound traffic
FW-UPDATE-4 |  | FIRST |  | New and updated rules shall only be accepted if two pins on the firewall are connected (shunted)
FW-UPDATE-5 |  | FIRST |  | New and updated rules shall only be accepted if the HMAC-SHA1 signature validation is successful
FW-UPDATE-6 |  | FIRST |  | New and updated rules shall only be accepted if they have been transmitted in whole, with all necessary CAN frames, from the Firewall Manager
FW-UPDATE-7 |  | FIRST |  | [MORE]
FW-TRAFFIC |  |  | Firewall Traffic management
FW-TRAFFIC-1 |  | FIRST |  | The Firewall shall process southbound traffic going from the IVI to the CAN network
FW-TRAFFIC-2 |  | FIRST |  | The Firewall shall process northbound traffic going from the CAN network to the IVI
FW-TRAFFIC-3 |  | FIRST |  | Each CAN frame, north- or south- bound, shall be filtered against the relevant rule set
FW-TRAFFIC-4 |  | FIRST |  | Each CAN frame shall be masked against the provisioned bit mask of a rule. | See http://www.cse.dmu.ac.uk/~eg/tele/CanbusIDandMask.html
FW-TRAFFIC-5 |  | FIRST |  | Each CAN frame shall have its masked result filtered aginst the bit filter of a rule. | See http://www.cse.dmu.ac.uk/~eg/tele/CanbusIDandMask.html
FW-TRAFFIC-6 |  | FIRST |  | If the filter operation returns non-zero the frame shall be processed according to the given rule
FW-TRAFFIC-7 |  | FIRST |  | [MORE]
FW-TRAFFIC-8 |  | FIRST |  | [Default rules]

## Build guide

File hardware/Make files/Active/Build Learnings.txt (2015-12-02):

ordered 1/3 of correct number of poly fuses
PDI and JTAG headers are upside down
FTDI TX and RX led labels are backwards

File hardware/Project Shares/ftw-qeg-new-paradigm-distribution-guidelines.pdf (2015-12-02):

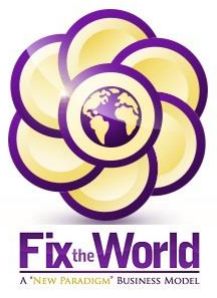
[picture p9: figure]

### FIX THE WORLD (FTW)

### Quantum Energy Generator (QEG)

### NEW PARADIGM DISTRIBUTION GUIDELINES

### TABLE OF CONTENTS:

INTRODUCTION
WHAT IS THE QEG? DESCRIPTION PATENTS
IMPORTANT HISTORY AND BACKGROUND
TESLA, EDISON, JP MORGAN
MAXWELL, EDISON, JP MORGAN AND THE LAWS OF PHYSICS THE FLIGHT OF THE BUMBLEBEE AND THE LAWS OF NATURE GOVERNMENT FUNDED RESEARCH AND HIGHER EDUCATION US PATENT OFFICE CLASSIFICATION SYSTEM

BARRIERS TO MARKET ENTRY
SUPPRESSION FROM COMPETING INTERESTS BELIEF SYSTEM / CONSCIOUSNESS / LAWS OF PHYSICS FINANCIAL CONTROL
CONTROLLING INTERESTS
PARANOIA, GREED, SECRECY

AREAS TO AVOID DURING QEG PRODUCTION AND DISTRIBUTION
GREED
ATTEMPTING TO MAKE A ‘STUPID’ PROFIT
PATENTING OR ATTEMPTING TO CLAIM SOLE OWNERSHIP OF THE QEG
MARKETING THE QEG THROUGH MAINSTREAM MEDIA
ATTEMPTING TO CONTROL, FORCE, CHANGE, OR CUT CORNERS DURING QEG PRODUCTION MASS PRODUCTION IN A LARGE CORPORATE ENVIRONMENT
DEPENDING ON A SINGLE FUNDER FOR QEG PRODUCTION

FTW QEG NEW PARADIGM DISTRIBUTION PLAN
THE POWER IS WITH THE PEOPLE
OPENSOURCE
LOCAL COTTAGE INDUSTRY PRODUCTION AND MYCELLINE DISTRIBUTION FTW GIVE BACK POLICY PROPOSAL
SPONSORSHIP PROGRAMS AND COMMUNITY CROWDFUNDING
START UP TRAINING PROGRAMS

### INTRODUCTION

The Fix the World Organization (FTW) is a services business for humanitarian projects. We have been developing a Quantum Energy Generator (QEG) as our pilot project to distribute to the world. The building of the QEG prototype was crowdfunded by hundreds of people that support this work. Now that the QEG is here, we have prepared this document to provide information and historical education on some important concepts around the QEG and to disclose our plans for distribution.

FTW intends to foster the development of Cottage Industry Community Units (CICU) for the production and distribution of QEG’s. To do this we will offer our consulting services for startup training programs and sponsorship programs. FTW will be manufacturing a limited number of QEG’s for sale to finance the creation of our CICU start-up trainings. FTW does not intend to be the sole manufacturer of the QEG, rather it is our top priority to put the QEG in the hands of the people and teach others how to make QEG’s for themselves.

WHAT IS THE QEG? DESCRIPTION

The Quantum Electric Generator system (QEG) is an adaptation of one of Nikola Tesla’s many patented electrical generator / dynamo / alternator designs. The particular patent referenced is No. 390,414, titled Dynamo-Electric Machine, and dated October 2, 1888.

The QEG prototype is scaled to produce electrical power in the range of 10-15 kW (kilowatts) continuously, and can be wired to provide either 120 Volt or 230-240 Volt single phase output. We are also planning future designs to provide 3-phase power.

Service life of the device is limited only by certain replaceable components, such as bearings, v-belts, and capacitors. The basic machine should operate trouble-free (with minimal maintenance) for as long as any good quality electro-mechanical appliance, such as a quality washing machine or refrigerator. Heavy-duty mechanical components are used throughout for reliability.

The QEG is not a complicated device, as it is designed (like Tesla’s other ‘discoveries’), to work in harmony with natural laws, rather than with the power-wasting symmetric motor and generator designs used in today’s mainstream industry.

An effective way to understand the operating principle of the QEG is to think of it as a high-powered, self-resonant oscillator (what used to be called a ‘multivibrator’), adapted to transform high-voltage pulses (15 to 25kV) into line voltage AC output, at current levels up to 120A. In today’s alternative energy terminology, it would be a type of resonance machine.

The circuitry that develops high power in this device is really based on an existing but under-utilized power oscillator configuration, however, the ‘quantum’ part of the design has to do with how the generator is started. Conventional alternators (AC generators) usually have a device called an ‘exciter coil’. This coil is usually a smaller, separate rotor winding that provides an AC voltage that is rectified and used to power the generator’s field coil(s).

In the QEG, there is no internal common exciter coil. In addition, to look at the circuit diagram, it is not apparent where the input power comes from to start resonance, and this is key; the QEG exciter coil is external to the generator, and the excitation signal is conducted through the quantum field (zero point) into the generator core, to start oscillation. Once the machine builds up to the resonant frequency, it powers itself (is self-running).

James M. Robitaille
Engineering Artist for the QEG Fix the World Council
February 10, 2014

## PATENTS

The QEG is a modern day artistic improvement on Tesla’s original engineering artwork, The Dynamo-Electric Machine, registered with the United States Patent Office #390414, and in the public domain.

The lifespan of design patents extend to 14 years, starting from the date of application rather than the date of approval. Patents protect the rights of the inventor, but at the same time the very purpose of issuing patents is to ‘promote science and useful arts’ wherein the inventor agrees to share (http://www.brighthub.com/office/entrepreneurs/articles/42924.aspx) the knowledge to the world after a period of exclusive right to commercially exploit the knowledge. Therefore, the inventor retains monopoly over the invention during the pendency of the patent. After expiry, the knowledge becomes public domain that anyone can access and use. The government makes public the description of the product, filed at the time of application. The inventor no longer has exclusive rights over the knowledge or invention, and anyone can access the patent office records (http://www.brighthub.com/office/entrepreneurs/articles/113089.aspx) and copy the invention.

The main content and claims of Tesla’s patents were recorded back in the late 1800s, therefore all main claims and or any improvements to rise around the original patented idea are in public domain.

The QEG is to be considered an improvement to a prior granted art. Therefore, the QEG must not be considered of enough grounds to obtain the granting of a unique art as is the granting of a patent anywhere on planet earth.

Furthermore, an improvement based on newer advanced technology to run, operate, or control the prior granted art should be classified also as non-patentable intellectual art.

The QEG, its blueprints, and user manual in its original entirety are to be considered new means for operating the prior granted art and based on the research and development of James M. Robitaille, Advanced Engineering Artist, FTW Organization, whose purpose and intention is to freely disclose it, open-source it, and share it with the world as Nikola Tesla intended.

It is understood that by making the QEG, its blueprints and user manual in its original entirety public and available to all, it is an ‘open sharing’ of an improvement on a public prior granted art and will be used as proof of prior existence by its permanent timestamp and links in many public and social networks where it has been uploaded, becoming non-changeable.

The QEG, its blueprints and user manual in their original entirety are an improvement on a public prior granted art that has been given freely and without prejudice to the people of planet earth. It can be replicated and distributed for the use of the people.

For supporting information please see:

http://www.brighthub.com/office/entrepreneurs/articles/42924.aspx

## IMPORTANT HISTORY AND BACKGROUND

TESLA, EDISON, and JP MORGAN

Nikola Tesla, (1856 -1943) was a trained electrical and mechanical engineer and one of the most influential inventors of the 20th century. Eventually holding over 700 patents, Tesla worked in a number of fields, including electricity, robotics, radar, and wireless transmission of energy. Tesla's discoveries laid the groundwork for many of the 20th century's technological advances. He is also known as the Father of AC Current, Father of the Radio, and The Man Who Invented the 20th Century.

In 1897 Nikola Tesla was involved in a DC vs. AC current war with Thomas Edison. Tesla was financially backed by Westinghouse to promote AC current, and Edison was financially backed by J.P. Morgan to promote DC current. AC current won the war and is still used to this day.

While Tesla’s AC current was only one of his many inventions, his true passion was to bring a source of energy to the world that would be freely available to everyone. However, J.P. Morgan told Tesla “If I can’t put a meter on it, it will never happen!” From that day forward, many of Tesla’s inventions, which were nonpolluting, worked according to the laws of nature and were intended for the benefit of humanity, would be stolen, suppressed, marginalized and removed from the public eye due to the financial interests of banking families such as J.P. Morgan and Rockefeller. Many of the inventions we all use today would not exist if it wasn’t for Tesla’s work. Many, such as Edison and Marconi, have stolen Tesla’s work and taken the credit.

The Fix The World Organization gives all credit for the QEG to Nikola Tesla. We are honored to act in service to carry on his great work in an effort to fulfill his (and others’) greatest desire: To bring his inventions to the people in this world that need them. The QEG is a modern day artistic improvement on Tesla’s original engineering artwork: Dynamo-Electric Machine, registered with the United States Patent Office #390414, and in the public domain. Please see the section on patents for more information.

For supporting information please see:

How J.P. Morgan and Rockefeller robbed you of your future. http://www.godlikeproductions.com/forum1/message1303381/pg1

The Secret Of Nikola Tesla-movie: http://www.youtube.com/watch?v=E46Rlw4GuFs

MAXWELL, EDISON, JP MORGAN AND THE LAWS OF PHYSICS

James Clerk Maxwell FRS FRSE (1831–1879) was a Scottish mathematical physicist. His most prominent achievement was to formulate a set of equations that describe electricity, magnetism, and optics as manifestations of the same phenomenon, namely the electromagnetic field. His discoveries helped usher in the era of modern physics, laying the foundation for such fields as special relativity and quantum mechanics.

In his ORIGINAL work: The Dynamical Theory of the Electromagnetic Field, Maxwell identified two separate systems, both of which were completely different from each other:

1) Asymmetrical system - an ‘open’ system that allows the creation of a series of exchange of energy reaction to our inputs, based on electromagnetic resonance or electromagnetic feedback in every spin (on a motor), or in every pulse of input in a static coil. One of the first asymmetrical motors was Faraday's ‘Unipolar Motor,’ later modified by Nikola Tesla. These systems generate their own energy and do not require fossil fuels.
2) Symmetrical system – a ‘closed’ system that cancels the electromagnetic resonance with every spin, which creates wasted energy in excessive heat and requires an additional energy source to run such as fossil fuels. These are the "symmetrical obsolete systems" we use every day in all of our electrical appliances.

One year after Maxwell’s death in 1879, scientists Hendrick Lorentz financed by J.P. Morgan and Thomas Edison, mutilated Maxwell’s original work and spent the next two decades deleting all knowledge of asymmetrical systems that would not require the profitable oil industry to operate. They ‘symmetrized’ all of Maxwell’s equations, and labeled these incomplete theories as the “Laws of Physics”. While the laws of physics do indeed apply to symmetrical closed systems of energy, there is another set of laws: The Laws of Nature, which apply to the asymmetrical systems that have been suppressed by the financial interests of the banking families for the last 130 years.

This knowledge was banned from our educational system, and no physics or electrical engineering school on our planet would ever teach about asymmetrical systems. Instead, the first and second laws of thermodynamics, which depend on the consumption of profitable fossil fuels, would conveniently prevail in our public knowledge base.

The QEG is an asymmetrical open system that operates according the laws of nature. It does not go against the laws of physics as these only apply to a closed symmetrical system.

For supporting information please see:

Symmetric Versus Asymmetric Electromagnetic Systems http://www.energeticforum.com/renewable-energy/11563-symmetric-versus-asymmetric-electromagnetic-systems.html (http://www.energeticforum.com/renewable-energy/11563-symmetric-versus-asymmetric-electromagnetic-systems.html)

Solving The World Energy Crisis: Some Ancillary Technical Information and Reference http://www.theorionproject.org/en/solving_bearden.html

THE FLIGHT OF THE BUMBLEBEE AND THE LAWS OF NATURE

The laws of physics tell us that perpetual motion is not possible, yet how does the earth rotate? The laws of aerodynamics tell us that bumblebees are incapable of flight, yet how do they fly?

Conventional scientists from all over the world will make statements such as: “The claim that this is going to run permanently or indefinitely doesn't seem to hold because the second law of thermodynamics tells us that this is not possible”

Around the turn-of-the-century eminent British scientist Lord Kelvin said “Radio has no future, heavier-than-air flying machines are impossible, and x-rays are a hoax” - so much for conventional science.

The laws of nature contain concepts that focus on frequency, resonation, vibration, magnetics and energy. A perfect example of this can be found in the aerodynamics-law-breaking flight of the bumblebee.

Ralph Ring is an innovative technician who worked with Otis T. Carr, a direct apprentice of Nikola Tesla. In his presentation at the Breakthrough Energy Movement Conference, Mr. Ring gives an amazing explanation of the flight of the bumblebee:

“Next to the larynx in the bumblebees throat, there is a tiny hollow tube that acts as a resonance cavity that accumulates frequency. When the bee starts beating its wings, it does this to accumulate frequency which bounces back and forth in the resonator cavity until it reaches the same frequency of the earth, known as the Schumann frequency. Once the bee reaches the same frequency as its surroundings it evens out into what is known as zero point. When anything reaches zero point you can then change the energy. The bee is now free from the gravitational influence around it, creates its own little magnetic bubble and hovers around. There are some lizards and hummingbirds that do the same thing.”

This is how the laws of nature work. When you can tune something to vibrate at the same frequency as the earth and reach zero point, you are freed from the frequency influence of your environment and can then change the energy into anything you want including levitation or electrical energy.

This is how the QEG works: Teslas design causes it to resonate so that it matches the frequency of the earth, and in zero point it changes the energy into self-renewing electrical energy.

For supporting information please see:

Ralph and Marsha Ring : Anti-gravity and Conscious Awareness in Aether Technology http://www.youtube.com/watch?v=8v3Bsh1E_8Y

GOVERNMENT FUNDED RESEARCH AND HIGHER EDUCATION

Most of the main stream scientific research and higher education systems today are funded by government grants and corporate interests. Such funding comes with a set of rules and regulations that must be followed in order to continue to receive that funding, even if the rules are unreasonable.

Some examples:

Harold Ashburton has an honors degree in engineering from Cambridge University and is also the retired head of IBM's European patent division. When presented with undeniable proof of a perpetual motion machine designed by John Searl he made the following statement:

“The government doesn't know about this work because the government only knows what their advisers tell them. Their advisers get money from the government and they want to keep getting the grants so they're not giving the advice they should from matters like this.”

Ralph Ring was a laboratory technician in a government-funded research and development laboratory in Costa Mesa, California. His job was to fire an electron through a magnetic field without deflection, and to do it the way they told him to do it. He was employed to repeat this experiment every day, which always failed, at a cost of $10,000 per day paid for by a government grant. He went home and replicated the experiment using the laws of nature and the experiment was successful. The next day he took his results to the head of the Department of Advanced Kinetics, Dr. Weinhart, who gave the following response:

“I see what you're doing there and I do understand, but Ralph what you don't understand is that this is a government-funded lab, and we are paid to look for answers, but not find them. Just go back to work and don't say anything to the engineers. This is not to be talked about at all.”

Unless the political and financial structure dramatically changes, a device like the QEG might not be supported by any individuals, companies, or organizations that rely on government funding to operate. Before introducing the QEG to any of these facilities, it is important to first identify their funding source and any associated barriers to acceptance.

For supporting information please see:

Ralph and Marsha Ring : Anti-gravity and Conscious Awareness in Aether Technology. http://www.youtube.com/watch?v=8v3Bsh1E_8Y

A Machine to Die For; The Quest For Free Energy http://www.youtube.com/watch?v=c6UgV3gVmd0

US PATENT OFFICE CLASSIFICATION SYSTEM

The U.S. Patent Office has a nine-member committee that screens patents in order to protect “national security”. Another purpose of this committee is to also find and remove from public access energy-related patents which could threaten the fossil fuel and power monopolies. Anytime someone applies for a patent, it goes through this screening process, if the device has anything to do with the production of “free energy” they classify it, confiscate it, conceal it in a vault and forbid the inventor to reproduce it.

In the documentary film titled, A Machine to Die For; The Quest For Free Energy, an ex-secret service agent assigned to electronic intelligence (whose identity was concealed) made the following statement:

“If you’re an idiot and try to go an patent your device, you’ve given them all your information on where you are and how to find you, and they will try to find some legal mechanism to close you down.”

One of many examples is Norman Watan, a free energy inventor who has come up against the patent office of America. His statement:

“In December 1994 we presented to the world a device known as the MRA which produces more output energy than the energy necessary to drive the circuit. It has been independently tested and verified by six different agencies with the final output figures being 256 times more energy out than energy in. This information was provided through the national security agency, who we strongly suspect, at the 11th hour caused the patent to be denied at the patent office and rejected with no explanation as to the reason for rejection.”

The QEG is a modern day artistic improvement on Tesla’s original engineering artwork: Dynamo-Electric Machine, registered with the United States Patent Office #390414, and in the public domain. Therefore, since a patent already exists there will be no renewed patent application process or its associated classification screening for the QEG. Please see the section on patents for more information.

For Supporting information please see:

Suppressed Energy Technologies: http://www.theorionproject.org/en/suppressed.html

PROTECTING THE PRIVATE INVENTOR UNDER THE PEACETIME http://www.handpen.com/Bio/patents.htm

A Machine to Die For. The Quest For Free Energy http://www.youtube.com/watch?v=c6UgV3gVmd0

## BARRIERS TO MARKET ENTRY

SUPPRESSION FROM COMPETING INTERESTS - as highlighted in the sections “TESLA, EDISON, JP MORGAN”, “MAXWELL, EDISON, JP MORGAN AND THE LAWS OF PHYSICS” “GOVERNMENT FUNDED RESEARCH AND HIGHER EDUCATION” and “US PATENT OFFICE CLASSIFICATION SYSTEM”

BELIEF SYSTEM - Since the knowledge of asymmetrical systems was banned from our educational
system, society has been trained to believe that such a concept is not possible, and tends to disregard ‘out-of-the-box’ thinking.

FINANCIAL CONTROL - Many inventors cannot obtain the financial resources necessary to get their invention developed. In most cases, where financial backing is offered, it is in exchange for complete control over the project, which most inventors will not agree to.

LACK OF PROOF OF PRINCIPLE- Proof of Principle constitutes a working prototype or plans that, when developed according to specifications, will result in a working prototype. Many inventions turn out to be just theories and not hardware. Unfortunately, there are some who take advantage of this and will scam investors, which creates a negative reputation around the entire free energy movement making it more difficult for legitimate inventors to succeed.

PARANOIA, GREED, SECRECY – Perhaps the most common, and biggest barriers of all. Most failures of getting a free energy device to market can be traced back to these three character traits exhibited by many inventors:

1. Paranoia - fear of retaliation or suppression from unknown sources
2. Greed - the desire to personally make millions from an unproven technology
3. Secrecy - fear their technology would be taken from them and they would receive little or no recognition or financial compensation for all their efforts

## AREAS TO AVOID DURING QEG PRODUCTION AND DISTRIBUTION

The following are some of the top areas that FTW highly suggests avoiding while producing and distributing the QEG. It has been our experience that these areas will not only make things more difficult, they can kill your QEG production project before it even begins. We provide our suggestions on the correct way to produce and distribute the QEG in later sections.

GREED
It is easy to become overwhelmed by the fantasy of making millions. Greed is a trap common to inventors. The moment you succumb to greed, it can curse your success. We have seen this way too many times with inventors. Don’t do it!

ATTEMPTING TO MAKE A ‘STUPID PROFIT’
Earning a profit from producing and selling a QEG can be expected and is encouraged. Profit is not a bad thing as long as it is part of healthy and natural economic growth and does not harm others. However, there is such a thing as ‘stupid profit,’ which can best be defined as the boundary crossed when it is no longer profit as a sign of healthy growth, but profit AT THE EXPENSE OF ANOTHER.

PATENTING OR ATTEMPTING TO CLAIM SOLE OWNERSHIP OF THE QEG – as mentioned in the patent section, the QEG cannot be patented because it has already been patented by Tesla, is in the public domain, and belongs to THE PEOPLE. If you attempt to patent the QEG, it is likely that you will suffer the same fate as the other 6,000 patents per year that are confiscated by the patent office as mentioned in the section “US PATENT OFFICE CLASSIFICATION SYSTEM”.

MARKETING THE QEG THROUGH MAINSTREAM MEDIA – Most of the thousands of mainstream networks (tv, print, entertainment) are owned by 6 corporations with conflicting interests,and many of them will not promote or report on the QEG. If by chance they did, it could possibly turn into a smear campaign in an effort to discredit the QEG, and protect the financial interests of the banking families that control the media.

ATTEMPTING TO CONTROL, FORCE, CHANGE, OR CUT CORNERS DURING QEG PRODUCTION – the QEG design is based on the laws of nature. When you try to control or force nature, she will not budge. Likewise, any form of manipulation of the QEG production could easily put the design out of its alignment with the laws of nature, and then the QEG won’t work.

MASS PRODUCTION IN A LARGE CORPORATE ENVIRONMENT – While it is very possible that this will be obtainable at some point in the future, there is a transition process that first needs to occur while QEGs are phased into society. This is best done through a small, direct cottage industry distribution network. At present, a large corporate environment may have too many restrictions and conflicting interests for the successful reproduction and distribution of QEG’s. The same can be said for attempting to produce the QEG in a government-funded facility.

DEPENDING ON A SINGLE FUNDER FOR QEG PRODUCTION - If at all possible, try to obtain a variety of financial supporters for the production of QEG’s in your area. Better yet, crowdfund it. Having one single funder who provides all the money leaves your QEG project vulnerable as that funder can change their mind, back out and kill the project in one fell swoop.

## FTW/QEG NEW PARADIGM DISTRIBUTION PLAN

THE POWER IS WITH THE PEOPLE

THE PEOPLE are the value on this planet. It is important to realize this as it will be through the people that innovations such as the QEG will breakthrough to the rest of humanity. It will not come from a major corporation or government.
THE PEOPLE built these devices in their garages, when government funded research labs would not. THE PEOPLE promoted the QEG on the internet, when the main stream media would not.
THE PEOPLE shared the technical knowledge in forums, when the education system would not.
THE PEOPLE crowdfunded the building of the QEG prototype, when the venture capitalists would not. THE PEOPLE supported the creation of the QEG from its inception to this day and NOW IT IS HERE.

Therefore, the QEG belongs to THE PEOPLE of planet earth, as they have birthed it into the world. THE PEOPLE will build QEG’s with their own hands for their communities.
THE PEOPLE will market the QEG through their social media networks.
THE PEOPLE will improve their own economies through QEG production.

We live in a world where:

In 10 years, over 40% of the Fortune 500 companies will no longer be here.
Millions of people have lost their jobs. They can create a job working on QEG’s.
Thousands of brilliant inventors have been ostracized. They can be vindicated through the QEG.

Social media is THE PEOPLES global voice, and it is where the QEG will spread to the whole of humanity through socialnomics, which is word of mouth on steroids.

Here are some examples that show the power of social media:
If Facebook where a country it would be the 3rd largest in the world.
Every minute, 72 hours of Video are uploaded to YouTube
Governments in Egypt toppled because of a tweet.
New Yorkers received a tweet about an earthquake, 30 seconds before they felt it.

The value is in THE PEOPLE and the power is in THE PEOPLE to bring the QEG to the world.

LOCAL COTTAGE INDUSTRY PRODUCTION AND MYCELLINE DISTRIBUTION

FTW plans to foster the development of Cottage Industry Community Units (CICUs) for the production and distribution of QEG’s. To do this we will offer our consulting services for startup training programs and sponsorship programs.

A cottage industry is an industry—primarily (http://en.wikipedia.org/wiki/Industry) manufacturing—which (http://en.wikipedia.org/wiki/Manufacturing) includes many producers, working from their homes, (http://en.wikipedia.org/wiki/House) typically part-time. (http://en.wikipedia.org/wiki/Part_time) Before the Industrial Revolution which eventually led to the state of centralized corporate manufacturing we live with today, most industries were cottage industries. The term originally referred to home workers who were engaged in a task such as sewing, (http://en.wikipedia.org/wiki/Sewing) lace-making, (http://en.wikipedia.org/wiki/Lace-making) wall hangings or household manufacturing. Business operators would travel around buying raw materials (http://en.wikipedia.org/wiki/Raw_material) and deliver them to people who would work on them, and then collect the finished goods to sell, or ship to another market.

The use of the term has expanded and is used to refer to any event which allows a large number of people to work part-time. For example, eBay (http://en.wikipedia.org/wiki/EBay) is said to have spawned a cottage industry of people who buy surplus merchandise, and sell it on their auction system.

A CICU for QEG production would need a business operator who could order raw materials to be delivered to the engineers that could work on assembling them in a local workshop or warehouse. Then, the business operator could sell the QEG’s to community members, and have them hand delivered and installed in homes or businesses by local QEG-trained electricians. This concept can be replicated in communities around the world.

Not only does this method provide QEG’s directly to the people, but it creates jobs, improves the local economy, restores the lost art of creativity and craftsmanship, and literally removes the ‘power’ from the corporations and gives it back to the people.

Mycelline Disribution is a term FTW is using to describe the way in which multiple cottage industry community units can connect around the globe. Mycelline refers to mycelium, which is the network of mushroom roots that grow beneath the surface. The knowledge of the existence of the QEG and the ability to create a cottage industry unit for its production and distribution in your community will spread by word of mouth, social media and “underground”, just like the mycelium. QEG’s, made by the people in their local communities will pop up everywhere from the network, just like mushrooms.

It is also worthy to mention that the primary role of fungi in an ecosystem is to decompose petroleum products and remove pollutants from the soil in a process known as bioremediation. This is perfect symbolism for bioremediation of the pollution caused by the big energy companies, as the QEG network decomposes and helps to phase out the petroleum industry.

OPEN-SOURCED

The blueprints, instructions and user manual in its original entirety will be publicly open-sourced. The QEG is an improvement on a public prior granted art by Nikola Tesla that is already in the public domain, and is given freely and without prejudice to the people of planet earth. It can be replicated and distributed for the use of the people.

Files containing the complete blueprints, instructions and user manual will be uploaded to open-source sites such as

It is understood that by making the QEG, its blueprints and user manual are in its original entirety, and public and available to all. These plans are an open sharing of an improvement on a public prior granted art, and will be used as proof of prior existence by its permanent timestamp and links in many public and social networks where it has been uploaded, becoming non-changeable.

The QEG, its blueprints and user manual in their original entirety are an improvement on a public prior granted art that has been given freely and without prejudice to the people of planet earth. It can be replicated and distributed for the use of the people.

The files will be uploaded and shared on sites such as keelynet.com (http://www.keelynet.com/share.htm ) according to their shareware proposal, and Sterling Allan’s Open Source Website: http://peswiki.com/index.php/Main_Page, as well as posted on numerous alternative blogs, websites and shared through social media platforms.

A waiver will be included with the files.

FTW GIVE BACK POLICY PROPOSAL

FTW is a services organization for humanitarian projects. The launch of QEG distribution is our pilot project. We currently have over 60 humanitarian projects collected that we would like to implement in the future. For example, one of our next intended projects includes amazing discoveries in healing that could cure people of terminal ‘incurable’ illnesses.

We have created a New Paradigm Business Model under which we choose to operate. Part of this model is a profit structure that flows according the laws of nature, and is based on givebacks and sharing. In nature there are stagnant ponds with only an inlet and no outlet, and living lakes that have an inlet and an outlet. An inflow and outflow of cash must be present in order for your project to be as alive and thriving as a living lake, and not a cesspool of a stagnant pond.

As FTW is openly sharing the QEG with the world, we would ask for those who benefit from this amazing contribution to humanity to give back to the FTW organization to help us launch our next amazing contribution to humanity.

A ‘Give Back’ is an agreed upon, ongoing endowment made to FTW from the future profits of CICU QEG production and distribution. A Give Back Agreement can be negotiated between FTW and any CICU in an amount that is comfortable for all. Part of this agreement includes a ‘pay-it-forward’ clause, which is a promise to create a sustainable benefit to others made possible by the CICU for their community, and FTW for using the give backs to support the funding of other projects that can be brought to the community in the future.

For more supporting information please see:

FTW New Paradigm Business Model http://hopegirl2012.files.wordpress.com/2013/01/fix-the-world-business-plan.pdf

A Profit Flow That Benefits All:
Profit generated through give back from large projects like the QEG will contribute towards additional projects that create a robust society of prosperous individuals who in turn will become the customer base for the purchase of QEG’s.

This is a system of positive energy flow. The QEG benefactors give to FTW, who then give to other communities, who then give back to the QEG benefactors. In these agreements everyone wins. This will maintain the sacred energy of giving, which in turn brings about receiving, which restores the healthy flow that has been cut off from our society for so long. This is how we can all become living lakes.

There will also be a shareware notice on the open sourced documents requesting the reader make a donation to FTW in appreciation for the sharing of QEG.

SPONSORSHIP PROGRAMS AND CROWDFUNDING

One QEG cost several thousand dollars to build, and will probably cost several thousand dollars to purchase when including a reasonable profit margin. While a one-time purchase of several thousand dollars is certainly economical when compared to a lifetime of utility bills, not everyone can afford this. For this reason FTW, would like to encourage the creation of sponsorship programs. Many wealthy individuals will be interested in purchasing a QEG for themselves, and CICU’s can offer incentives to these individuals to sponsor the cost of one or more QEG’s to be donated to a community or individual that cannot afford them.

Another alternative is crowdfunding. Any individual, business, or community can raise funds to purchase a QEG through crowdfunding platforms like gofundme or indegogo.

START UP TRAINING PROGRAMS

Wherever possible, FTW would like to offer our consulting services in person to assist in CICU startups around the world. Initially, FTW will be manufacturing a limited number of QEG’s for sale to finance the creation of our CICU start-up trainings. FTW does not intend to be the sole manufacturer of the QEG, rather it is our top priority to put the QEG in the hands of the people and teach others how to make QEGs for themselves.

A CICU start-up training session would consist of:

- On-site, hands-on training of engineers and business operators involved in local QEG production given by the Engineering Artist James Robitaille and HopeGirl. Learn how to assemble your QEGs to ensure that they work properly, and learn how to effectively sell them, distribute them, install them, and service them. Also, learn how to create sponsorship programs and crowdfunding campaigns to make them more affordable to members of your community.

We also intend to hold future train-the-trainer sessions to teach others how to conduct their own CICU start-up training.

WANT TO START UP YOUR OWN CICU FOR QEG PRODUCTION?

Below are some of the first things you’ll need to start up your own CICU for QEG production. (These needs may change and grow as the program rolls out.)

- Funding to purchase materials, pay engineers, buy tools etc. Communities can pool their resources.
- A workshop, garage or warehouse to produce QEG’s. Some place with adequate privacy would work best.
- One or more designated business operators to manage the CICU.
- A small team of skilled engineers (one or two) who are willing to build them. Check Keelynet.com or other sources to find a string of engineers who understand these ‘new’ laws of physics, who have dedicated their lives for just the opportunity to do something like this.
- A supplier to cut the core parts to spec. (laser precision cutting of steel). FTW can give you some leads.
- A toroidal-winding machine or service that can do a custom winding job for a large core.
- A small network of electricians that can be trained to install and deliver QEGs (relatively simple process)
- A generator converter switch to hook up to the main power supply of the house.
- A network to communicate with your customer base. This will spread by word of mouth and by social media. It will not be advertised or marketed on main stream anything.
- A policy of some sort according to your own community guidelines for returns or product servicing.

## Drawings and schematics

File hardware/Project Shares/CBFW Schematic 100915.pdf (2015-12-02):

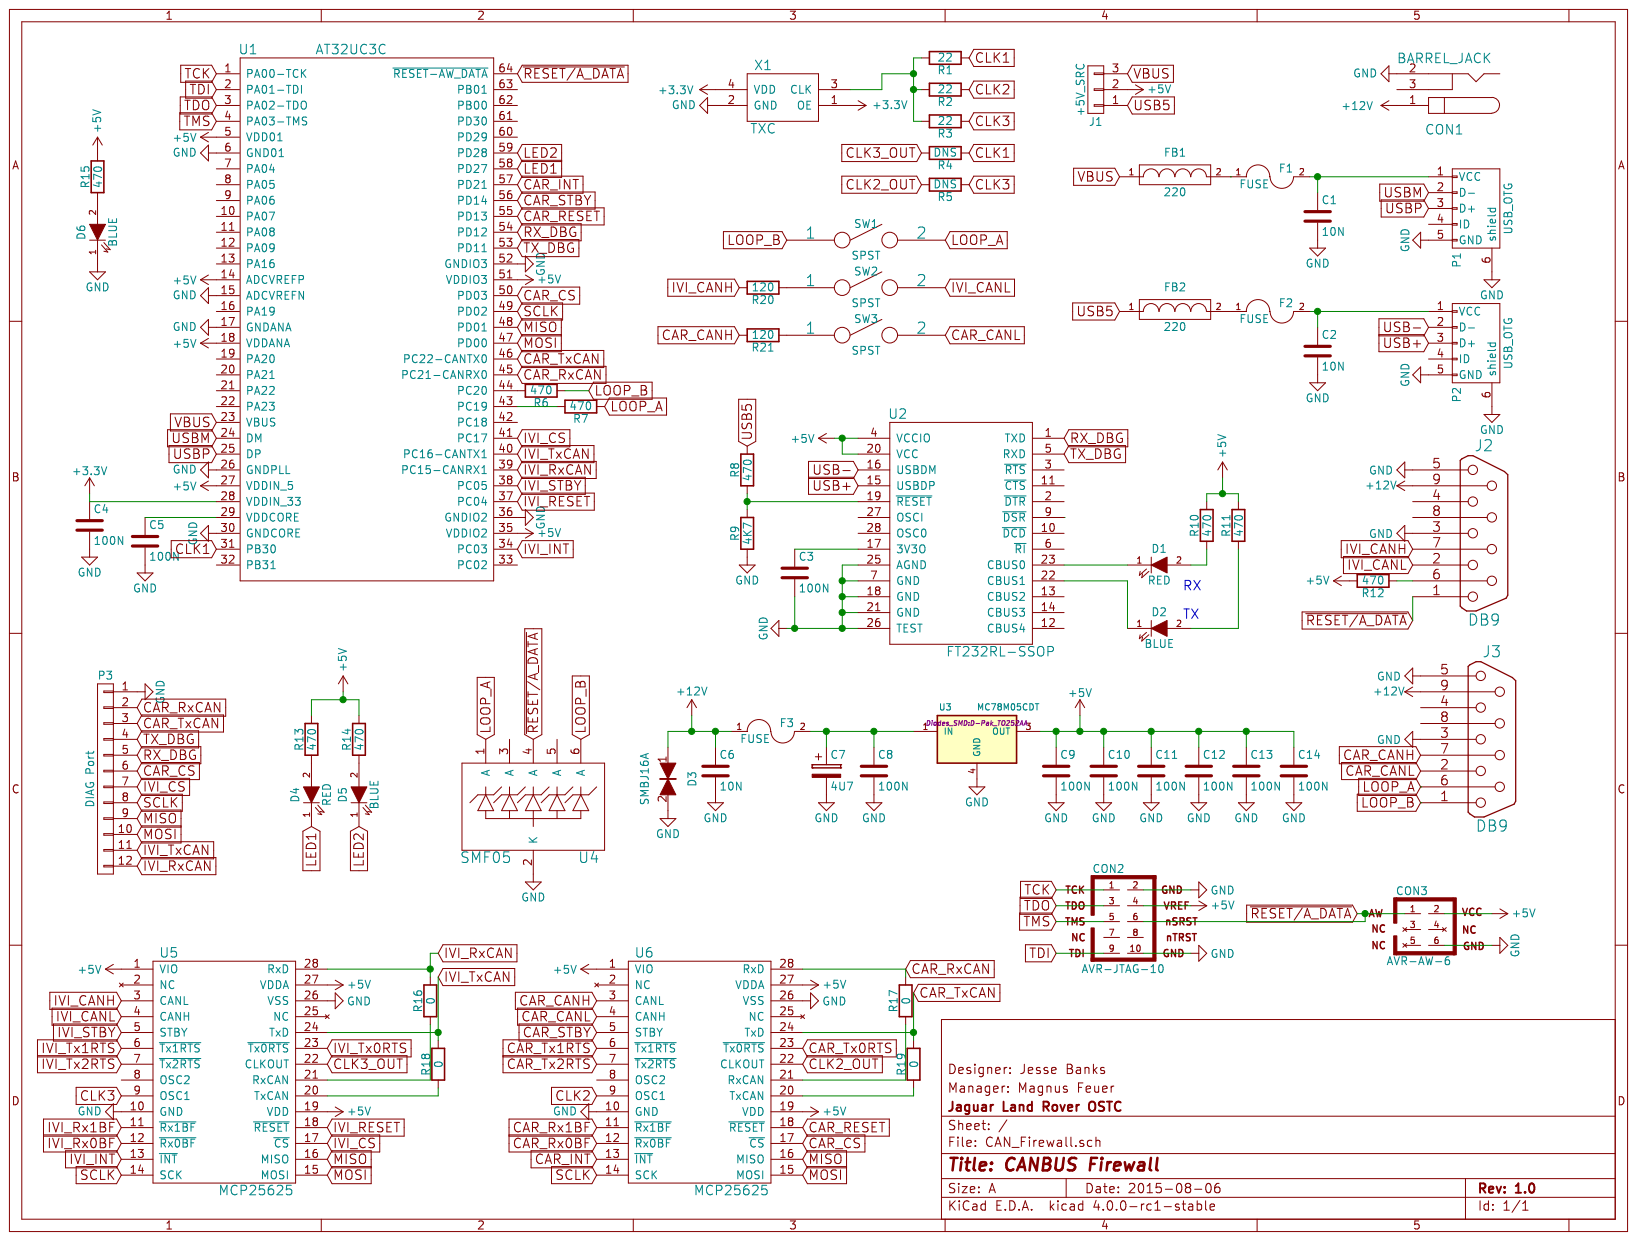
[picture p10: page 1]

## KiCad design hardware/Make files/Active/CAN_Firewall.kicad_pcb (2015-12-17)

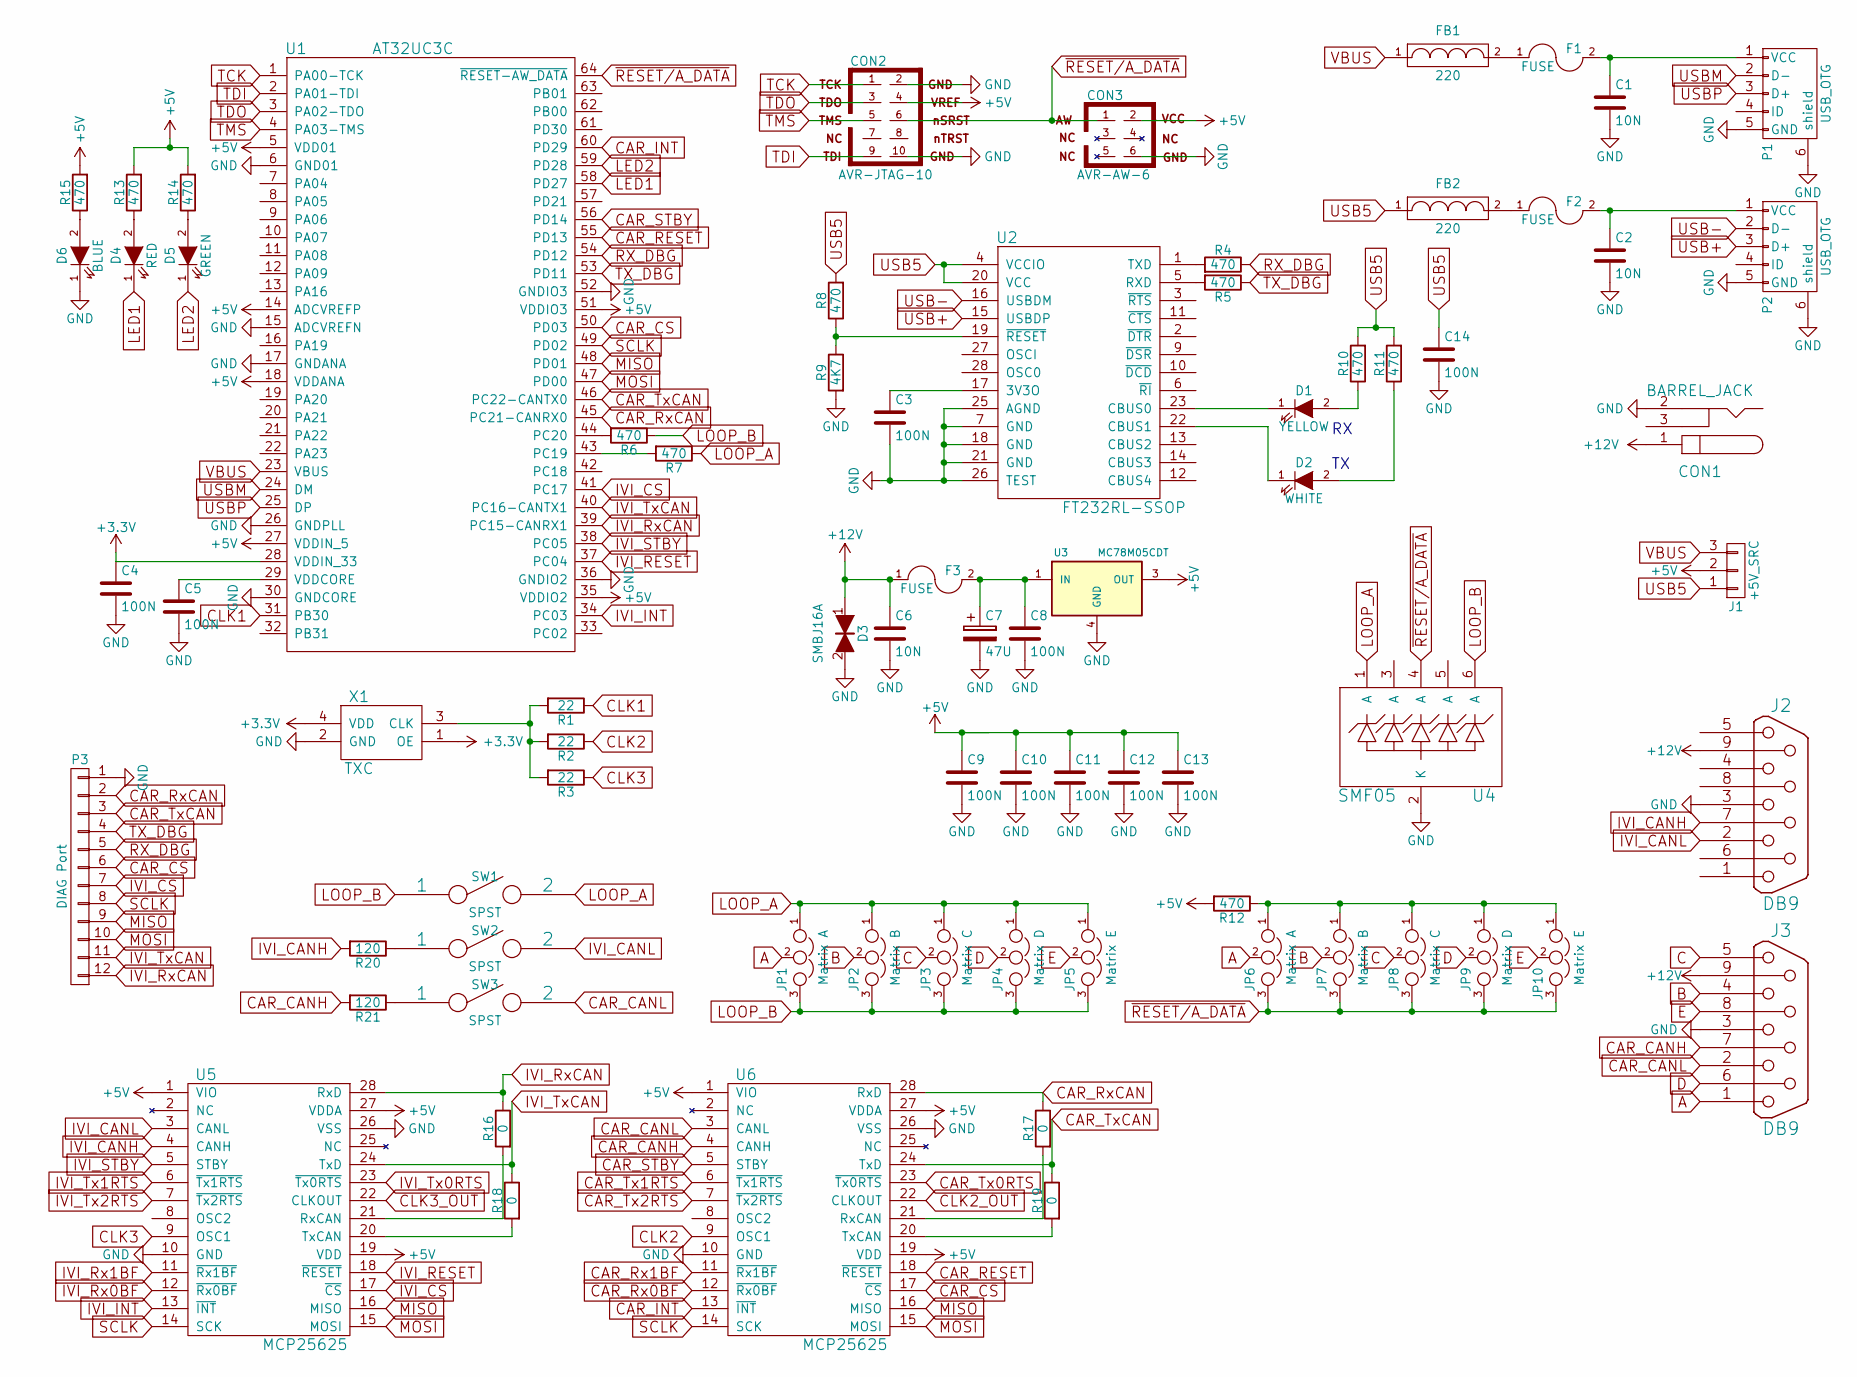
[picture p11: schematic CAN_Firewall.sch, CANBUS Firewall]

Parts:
C1, C2, C6: 10N; R_0603_sm; Mouser 77-VJ0603Y103KXACBC
C3, C4, C5, C8, C9, C10, C11, C12, C13, C14: 100N; R_0603_sm; Mouser 581-06035C104KAT2A
C7: 47U; c_elec_6.3x5.3; Mouser 140-VE470M1ETR0605
CON1: BARREL_JACK; Mouser 502-RAPC722X
CON2: AVR-JTAG-10; Socket_Strip_Straight_2x05
CON3: AVR-AW-6; Socket_Strip_Straight_2x03; Mouser 855-M20-9980346
D1: YELLOW; Diode_0805_12; Mouser 630-HSMY-C170
D2: WHITE; Diode_0805_12; Mouser 859-LTW-170ZDC
D3: SMBJ16A; SMB_Handsoldering; Mouser 511-SMBJ16A
D4: RED; Diode_0805_12; Mouser 630-HSMH-C170
D5: GREEN; Diode_0805_12; Mouser 630-HSMG-C170
D6: BLUE; Diode_0805_12; Mouser 630-HSMR-C170
F1, F2, F3: FUSE; R_1210_SM; Mouser 530-0ZCH0050FF2G
FB1, FB2: 220; Diode_0805_12_SM; Mouser 810-MPZ1608S221ATA00
J1: +5V_SRC; Socket_Strip_Straight_1x03; Mouser 855-M20-9990346
J2, J3: DB9; DB9F_CI; Mouser 523-L77-DE09S
JP1, JP6: Matrix A; GS3
JP2, JP7: Matrix B; GS3
JP3, JP8: Matrix C; GS3
JP4, JP9: Matrix D; GS3
JP5, JP10: Matrix E; GS3
P1, P2: USB_OTG; USB_Micro-B-DX4R005JJ2R1800; Mouser 656-DX4R005JJ2R1800
P3: DIAG Port; Socket_Strip_Straight_1x12; Mouser 855-M20-9991246
R1, R2, R3: 22; R_0603_sm; Mouser 71-CRCW0603-22.1-E3
R4, R5, R6, R7, R8, R10, R11, R12, R13, R14, R15: 470; R_0603_sm; Mouser 71-CRCW0603-470-E3
R9: 4K7; R_0603_sm; Mouser 71-CRCW0603-4.7K-E3
R16, R17, R18, R19: 0; R_0603_sm; Mouser 71-CRCW0603-0-E3
R20, R21: 120; R_0603_sm; Mouser 71-CRCW0603-120-E3
SW1, SW2, SW3: SPST; SW_SPST_FSMSM_SM; Mouser 653-A6TN-1104
U1: AT32UC3C; LQFP-64_10x10mm_Pitch0.5mm; Mouser 556-AT32UC3C2512CA2T
U2: FT232RL-SSOP; SSOP-28_5.3x10.2mm_Pitch0.65mm; Mouser 895-FT232RL
U3: MC78M05CDT; D-Pak_TO252AA; Mouser 511-L78M05CDT-TR
U4: SMF05; SC-70-6; Mouser 863-SMF05CT2G
U5, U6: MCP25625; SSOP-28_5.3x10.2mm_Pitch0.65mm; Mouser MCP25625-E/SS
X1: TXC; Mouser 634-501BAA16M0000CAG

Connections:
+3V3: C4.1, U1.28 (VDDIN_33), X1.1 (OE), X1.4 (VDD)
+5V: C9.1, C10.1, C11.1, C12.1, C13.1, CON2.4, CON3.2, J1.2, R12.2, R13.2, R14.2, R15.2, U1.5 (VDD01), U1.14 (ADCVREFP), U1.18 (VDDANA), U1.27 (VDDIN_5), U1.35 (VDDIO2), U1.51 (VDDIO3), U3.3 (OUT), U5.1 (VIO), U5.19 (VDD), U5.27 (VDDA), U6.1 (VIO), U6.19 (VDD), U6.27 (VDDA)
+12V: C6.1, CON1.1, D3.1, F3.1, J2.9, J3.9
A: J3.1, JP1.2, JP6.2
B: J3.4, JP2.2, JP7.2
C: J3.5, JP3.2, JP8.2
CAR_CANH: J3.7, R21.2, U6.4 (CANH)
CAR_CANL: J3.2, SW3.2, U6.3 (CANL)
CAR_CS: P3.6, U1.50 (PD03), U6.17 (~CS)
CAR_INT: U1.60 (PD29), U6.13 (~INT)
CAR_RESET: U1.55 (PD13), U6.18 (~RESET)
CAR_Rx0BF: U6.12 (~Rx0BF)
CAR_Rx1BF: U6.11 (~Rx1BF)
CAR_RxCAN: P3.2, R17.1, U1.45 (PC21-CANRX0), U6.28 (RxD)
CAR_STBY: U1.56 (PD14), U6.5 (STBY)
CAR_Tx0RTS: U6.23 (~Tx0RTS)
CAR_Tx1RTS: U6.6 (~Tx1RTS)
CAR_Tx2RTS: U6.7 (~Tx2RTS)
CAR_TxCAN: P3.3, R19.1, U1.46 (PC22-CANTX0), U6.24 (TxD)
CLK1: R1.1, U1.31 (PB30)
CLK2: R2.1, U6.9 (OSC1)
CLK2_OUT: U6.22 (CLKOUT)
CLK3: R3.1, U5.9 (OSC1)
CLK3_OUT: U5.22 (CLKOUT)
D: J3.6, JP4.2, JP9.2
E: J3.8, JP5.2, JP10.2
GND: C1.2, C2.2, C3.2, C4.2, C5.2, C6.2, C7.2, C8.2, C9.2, C10.2, C11.2, C12.2, C13.2, C14.2, CON1.2, CON2.2, CON2.10, CON3.6, D3.2, D6.1 (K), J2.3, J3.3, P1.5 (GND), P1.6 (shield), P2.5 (GND), P2.6 (shield), P3.1, R9.2, U1.6 (GND01), U1.15 (ADCVREFN), U1.17 (GNDANA), U1.26 (GNDPLL), U1.30 (GNDCORE), U1.36 (GNDIO2), U1.52 (GNDIO3), U2.7 (GND), U2.18 (GND), U2.21 (GND), U2.25 (AGND), U2.26 (TEST), U3.4 (GND), U4.2 (K), U5.10 (GND), U5.26 (VSS), U6.10 (GND), U6.26 (VSS), X1.2 (GND)
IVI_CANH: J2.7, R20.2, U5.4 (CANH)
IVI_CANL: J2.2, SW2.2, U5.3 (CANL)
IVI_CS: P3.7, U1.41 (PC17), U5.17 (~CS)
IVI_INT: U1.34 (PC03), U5.13 (~INT)
IVI_RESET: U1.37 (PC04), U5.18 (~RESET)
IVI_Rx0BF: U5.12 (~Rx0BF)
IVI_Rx1BF: U5.11 (~Rx1BF)
IVI_RxCAN: P3.12, R16.1, U1.39 (PC15-CANRX1), U5.28 (RxD)
IVI_STBY: U1.38 (PC05), U5.5 (STBY)
IVI_Tx0RTS: U5.23 (~Tx0RTS)
IVI_Tx1RTS: U5.6 (~Tx1RTS)
IVI_Tx2RTS: U5.7 (~Tx2RTS)
IVI_TxCAN: P3.11, R18.1, U1.40 (PC16-CANTX1), U5.24 (TxD)
LED1: D4.1 (K), U1.58 (PD27)
LED2: D5.1 (K), U1.59 (PD28)
LOOP_A: JP1.1, JP2.1, JP3.1, JP4.1, JP5.1, R7.1, SW1.2, U4.1 (A)
LOOP_B: JP1.3, JP2.3, JP3.3, JP4.3, JP5.3, R6.1, SW1.1, U4.6 (A)
MISO: P3.9, U1.48 (PD01), U5.16 (MISO), U6.16 (MISO)
MOSI: P3.10, U1.47 (PD00), U5.15 (MOSI), U6.15 (MOSI)
unnamed: C1.1, F1.2, P1.1 (VCC)
unnamed: C2.1, F2.2, P2.1 (VCC)
unnamed: C3.1, U2.17 (3V3O)
unnamed: C5.1, U1.29 (VDDCORE)
unnamed: C7.1, C8.1, F3.2, U3.1 (IN)
unnamed: D1.1 (K), U2.23 (CBUS0)
unnamed: D1.2 (A), R10.1
unnamed: D2.1 (K), U2.22 (CBUS1)
unnamed: D2.2 (A), R11.1
unnamed: D4.2 (A), R13.1
unnamed: D5.2 (A), R14.1
unnamed: D6.2 (A), R15.1
unnamed: F1.1, FB1.2
unnamed: F2.1, FB2.2
unnamed: JP6.1, JP7.1, JP8.1, JP9.1, JP10.1, R12.1
unnamed: R1.2, R2.2, R3.2, X1.3 (CLK)
unnamed: R4.2, U2.1 (TXD)
unnamed: R5.2, U2.5 (RXD)
unnamed: R6.2, U1.44 (PC20)
unnamed: R7.2, U1.43 (PC19)
unnamed: R8.1, R9.1, U2.19 (~RESET)
unnamed: R16.2, U5.21 (RxCAN)
unnamed: R17.2, U6.21 (RxCAN)
unnamed: R18.2, U5.20 (TxCAN)
unnamed: R19.2, U6.20 (TxCAN)
unnamed: R20.1, SW2.1
unnamed: R21.1, SW3.1
RX_DBG: P3.5, R4.1, U1.54 (PD12)
SCLK: P3.8, U1.49 (PD02), U5.14 (SCK), U6.14 (SCK)
TCK: CON2.1, U1.1 (PA00-TCK)
TDI: CON2.9, U1.2 (PA01-TDI)
TDO: CON2.3, U1.3 (PA02-TDO)
TMS: CON2.5, U1.4 (PA03-TMS)
TX_DBG: P3.4, R5.1, U1.53 (PD11)
USB5: C14.1, FB2.1, J1.1, R8.2, R10.2, R11.2, U2.4 (VCCIO), U2.20 (VCC)
USB+: P2.3 (D+), U2.15 (USBDP)
USB-: P2.2 (D-), U2.16 (USBDM)
USBM: P1.2 (D-), U1.24 (DM)
USBP: P1.3 (D+), U1.25 (DP)
VBUS: FB1.1, J1.3, U1.23 (VBUS)
~RESET/A_DATA: CON2.6, CON3.1, JP6.3, JP7.3, JP8.3, JP9.3, JP10.3, U1.64 (~RESET-AW_DATA), U4.4 (A)

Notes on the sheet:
RX TX

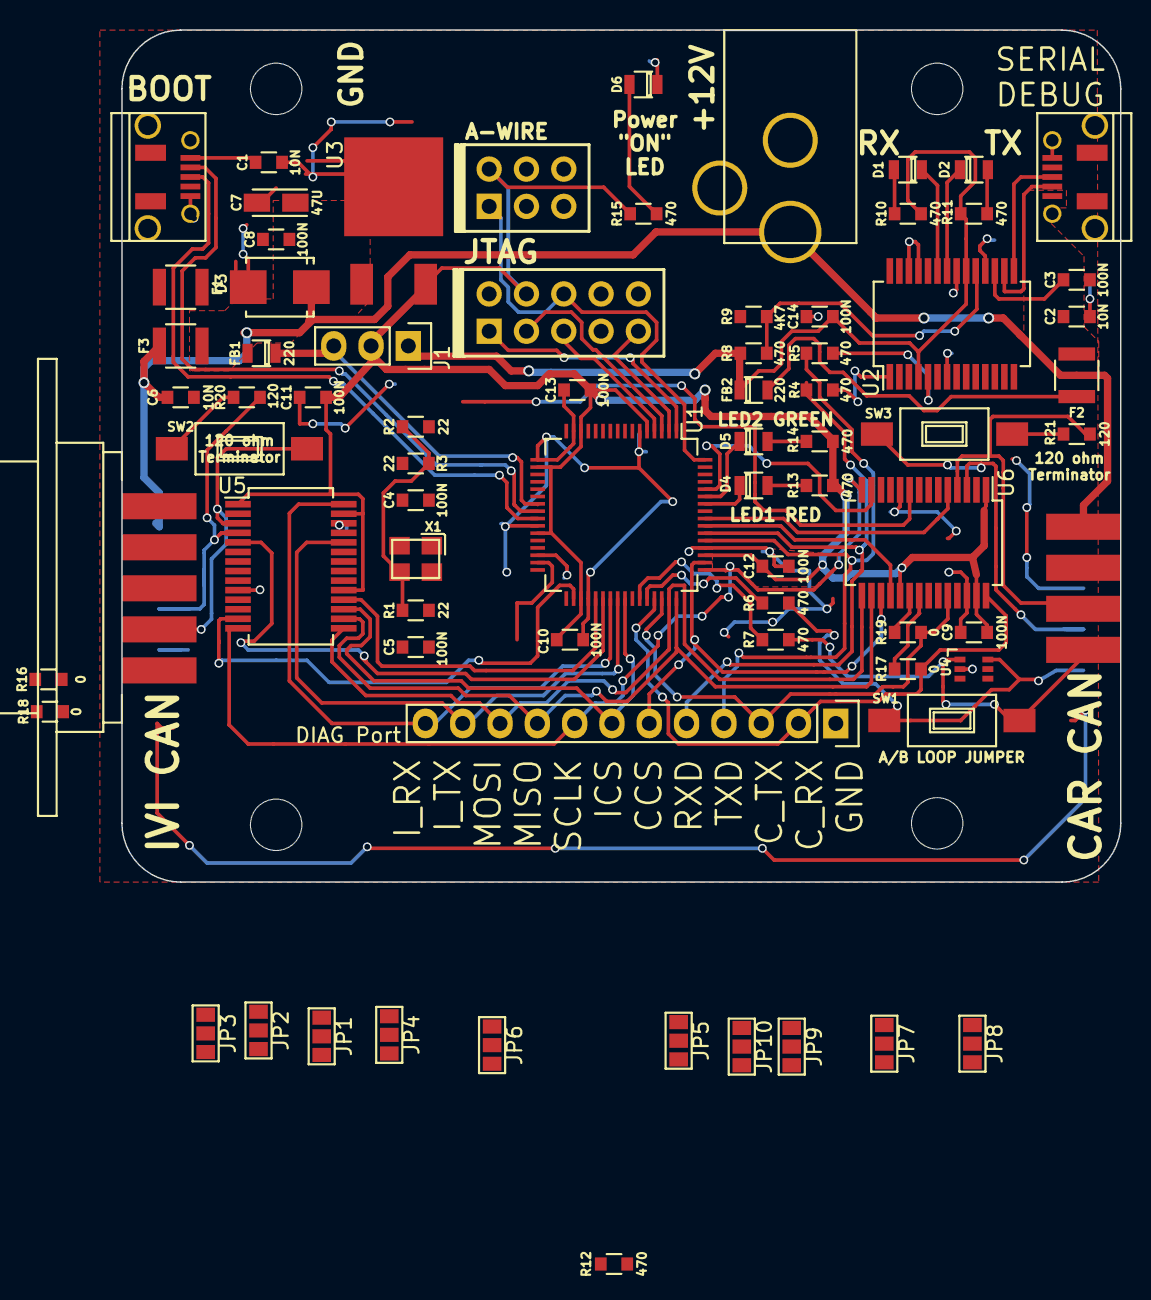
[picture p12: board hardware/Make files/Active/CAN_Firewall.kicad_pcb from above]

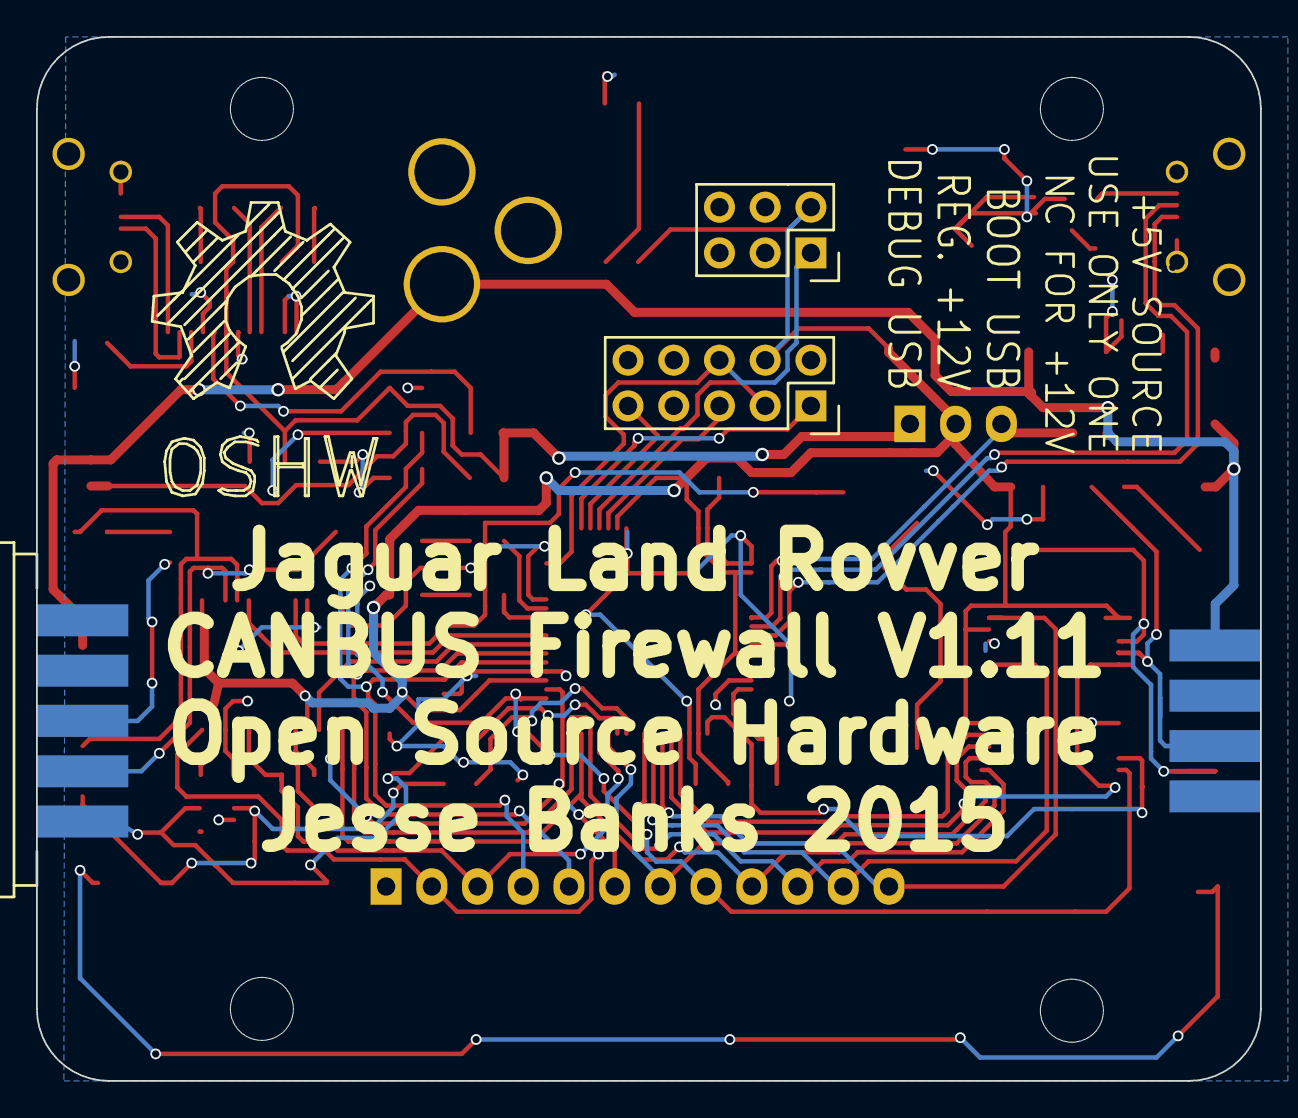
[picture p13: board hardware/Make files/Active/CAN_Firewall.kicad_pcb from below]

Board: 2 copper layers, 68.0 x 58.0 mm, 75 parts (3 on the bottom side), 75 nets.

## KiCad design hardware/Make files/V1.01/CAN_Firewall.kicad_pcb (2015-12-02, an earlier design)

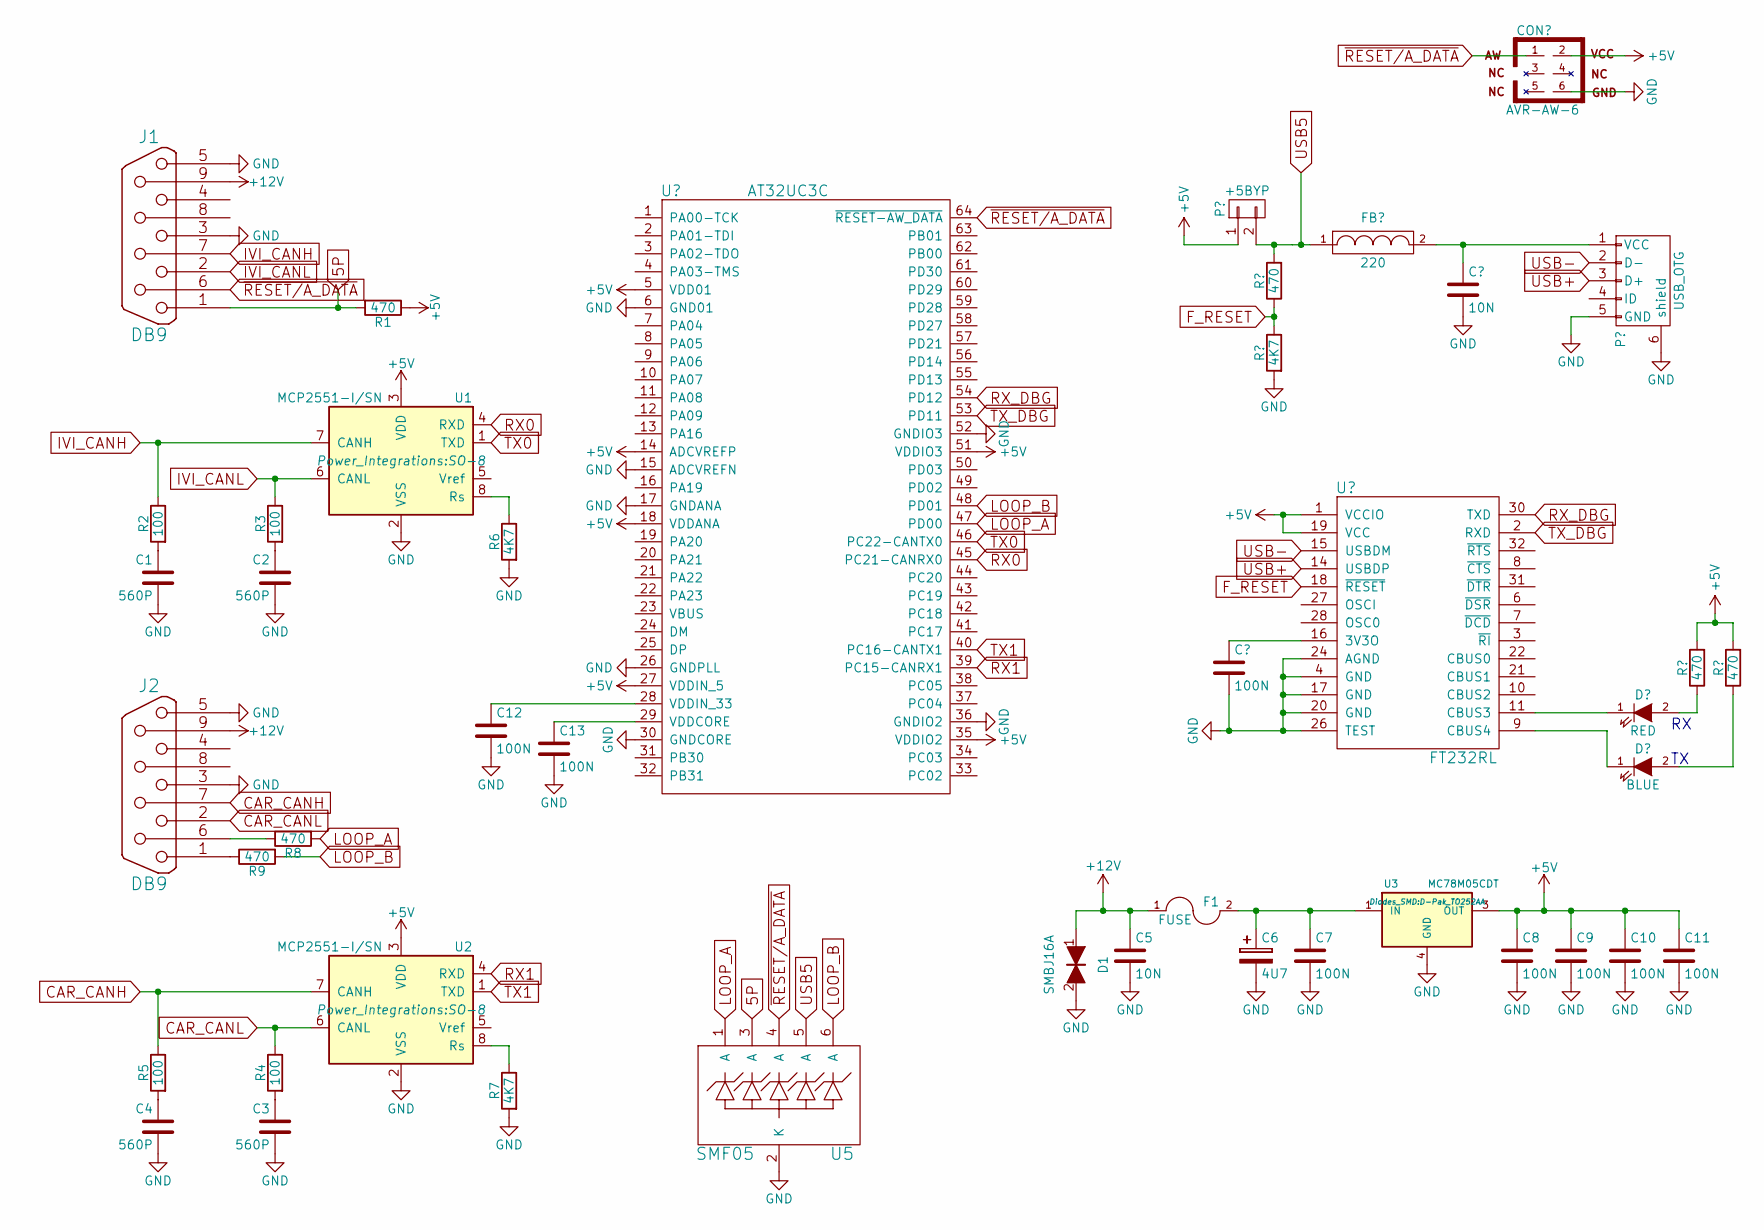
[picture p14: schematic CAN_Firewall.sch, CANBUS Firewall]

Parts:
C1, C2, C3, C4: 560P; R_0603_sm
C5: 10N; R_0603_sm
C6: 4U7; TantalC_SizeA_EIA-3216_Reflow
C7, C8, C9, C10, C11, C12, C13: 100N; R_0603_sm
D1: SMBJ16A; Diode-SMB_Standard
F1: FUSE; R_1210_SM
J1, J2: DB9; DB9F_CI
R1, R8, R9: 470; R_0603_sm
R2, R3, R4, R5: 100; R_0603_sm
R6, R7: 4K7; R_0603_sm
U1, U2: MCP2551-I/SN; SO-8
U3: MC78M05CDT; D-Pak_TO252AA
U5: SMF05; SC-70-6

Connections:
5P: J1.1, R1.2, U5.3 (A)
+5V: C8.1, C9.1, C10.1, C11.1, R1.1, U1.3 (VDD), U2.3 (VDD), U3.3 (OUT); also elsewhere on the board
+12V: C5.1, D1.1, F1.1, J1.9, J2.9; also elsewhere on the board
A_DATAOUT: J1.8, U5.5 (A); also elsewhere on the board
CAR_CANH: J2.7, R5.1, U2.7 (CANH)
CAR_CANL: J2.2, R4.1, U2.6 (CANL)
GND: C1.2, C2.2, C3.2, C4.2, C5.2, C6.2, C7.2, C8.2, C9.2, C10.2, C11.2, C12.2, C13.2, D1.2, J1.3, J1.5, J2.3, J2.5, R6.2, R7.2, U1.2 (VSS), U2.2 (VSS), U3.4 (GND), U5.2 (K); also elsewhere on the board
IVI_CANH: J1.7, R2.1, U1.7 (CANH)
IVI_CANL: J1.2, R3.1, U1.6 (CANL)
LOOP_A: R8.2, U5.1 (A); also elsewhere on the board
LOOP_B: R9.2, U5.6 (A); also elsewhere on the board
unnamed: C1.1, R2.2
unnamed: C2.1, R3.2
unnamed: C3.1, R4.2
unnamed: C4.1, R5.2
unnamed: C6.1, C7.1, F1.2, U3.1 (IN)
unnamed 16: C12.1; also elsewhere on the board
unnamed 17: C13.1; also elsewhere on the board
unnamed: J2.1, R9.1
unnamed: J2.6, R8.1
unnamed: R6.1, U1.8 (Rs)
unnamed: R7.1, U2.8 (Rs)
RX0: U1.4 (RXD); also elsewhere on the board
RX1: U2.4 (RXD); also elsewhere on the board
TX0: U1.1 (TXD); also elsewhere on the board
TX1: U2.1 (TXD); also elsewhere on the board
~RESET/A_DATA: J1.6, U5.4 (A); also elsewhere on the board

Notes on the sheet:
RX TX

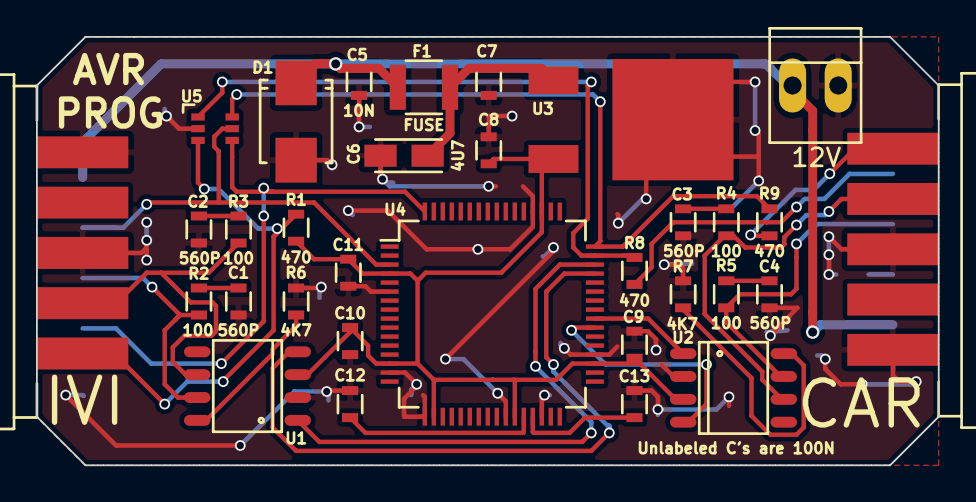
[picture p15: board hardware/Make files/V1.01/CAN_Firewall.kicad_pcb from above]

Board: 2 copper layers, 50.1 x 23.8 mm, 32 parts (0 on the bottom side), 27 nets.

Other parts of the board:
12V: PINHEAD1-2
U4: AT32UC3C; LQFP-64_10x10mm_Pitch0.5mm

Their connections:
+5V: U4.4, U4.14, U4.18, U4.27, U4.35, U4.51; also elsewhere on the board
+12V: 12V.1; also elsewhere on the board
A_DATAOUT: U4.3; also elsewhere on the board
GND: 12V.2, U4.6, U4.15, U4.17, U4.26, U4.30, U4.36, U4.52; also elsewhere on the board
LOOP_A: U4.47; also elsewhere on the board
LOOP_B: U4.48; also elsewhere on the board
unnamed 16: U4.28; also elsewhere on the board
unnamed 17: U4.29; also elsewhere on the board
RX0: U4.45; also elsewhere on the board
RX1: U4.39; also elsewhere on the board
TX0: U4.46; also elsewhere on the board
TX1: U4.40; also elsewhere on the board
~RESET/A_DATA: U4.64; also elsewhere on the board

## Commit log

2015-08-11 Initial version of presentation and DRD
    [DRD_CANFW.xlsx]
2015-08-11 Added first spin of hardware
    [CAN_FW_BOM_DL.xls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]
2015-08-13 Including all files from jesse
    Updated with my current changes since I sent the HW package over thumb
    drive to Magnus.
    Did some V1->V2 cleanup with files and folders
    [CAN_Firewall (2).kicad_pcb, CAN_Firewall (2).sch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]
2015-08-13 V1.1 Devlopment
    Created teh V1.1 hardware files. The Hardware patch for V1 will follow
    this design.
    [CAN_Firewall (2).kicad_pcb, CAN_Firewall (2).sch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]
2015-08-14 V1.1 Diag port improved
    added another resistor in the Loop B input, to facilitate a "bypass
    mode" in conjunction with a "rule learn mode".
    [CAN_FW_V1.1_BOM_DL.xls, CAN_FW_V1_BOM_DL.xls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]
2015-08-24 exploring the fixes for the proto
    made a rudimentary design to copy when building the CBFW proto, as it
    requires modifications.
    [CAN_Firewall.sch]
2015-08-31 Little endian of all bitfields. Fixed HMAC length
    All multi-frame bitfields are now little endian to facilitate easy roll
    out in memory.
    Removed unused1 and expanded HMAC to 256 bits (was 240 bits)
2015-09-08 Cleanup of files, V1.1 Schematic Dev
    Cleaned up files and folders
    dev of new hardware
    [CAN_FW_BOM_DL.xls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]
2015-09-10 V1.1 layout pass complete
    [CAN_Firewall-B_Cu.gbl, CAN_Firewall-B_Mask.gbs, CAN_Firewall-B_SilkS.gbo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]
2015-09-10 folders updated for another subrev of PCB
    [CAN_Firewall.kicad_pcb, CAN_Firewall.sch]
2015-09-10 V1.11 Schematic and PCB layout
    [CAN_FW_V1.11_BOM.xls, CAN_Firewall.sch]
2015-09-14 V1.11 Proofed
    Ready to order
    [CAN_FW_V1.11_BOM.xls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]
2015-10-26 Prep for next rev
    found a HW flaw, made fixes
    [CAN_Firewall.kicad_pcb, CAN_Firewall.sch]
2015-10-26 Fixed CanH-CanL swap
    [CAN_Firewall-B_Cu.gbl, CAN_Firewall-B_Mask.gbs, CAN_Firewall-B_SilkS.gbo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]
2015-11-03 Moved CAR Interupt signal to different Pin
    Steve needed the car side can controller interupt signal to go to a
    different pin because of some inherent traits of the original pin
    [CAN_Firewall.kicad_pcb, CAN_Firewall.sch]
2015-12-17 progress towards V1.2
    [CAN_Firewall.kicad_pcb, CAN_Firewall.sch]
